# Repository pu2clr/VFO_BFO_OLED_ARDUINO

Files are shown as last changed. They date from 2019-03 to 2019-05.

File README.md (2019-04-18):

# VFO and BFO with Si5351A, OLED and Arduino

## By PU2CLR - Ricardo Lima Caratti - March 18th, 2019

__Português:__ Gerador de Sinal com Si5341, OLED e Arduino. Este projeto é sobre a construção de um VFO (530KHz to 160MHz) e um BFO (452KHz to 458KHz). Para mais detalhes consulte a [documentação em Português](/Doc/Pt). 

__English:__ Signal Generetor with Si5351, OLED and Arduino. This project is about a construction of a VFO (530KHz to 160MHz) and a BFO (452KHz to 458KHz or another range). See [documentation here](/Doc/En).

## Table of contents

1. [Introduction](/Doc/En#introduction) 
1. [Arduino ATmega32U4](/Doc/En#arduino-atmega32u4)
1. [BFO interface](/Doc/En#vfo-and-bfo-interface)
	1. [VFO and BFO and Dial information](/Doc/En#vfo-and-bfo-and-dial-information)
1. [Band table for the VFO](/Doc/En#band-table-for-the-VFO)
1. [Schematic](/Doc/En#schematic)
1. [Components](/Doc/En#components)
1. [Arduino sketch](/Doc/En#arduino-sketch)
	1. [BFO range](/Doc/En#bfo-range)
	1. [Arduino pins and  Encoder, Band, Step and Switch VFO/BFO](/Doc/En#arduino-pins-and--encoder-band-step-and-switch-vfobfo)
	1. [Bands and frequency ranges](/Doc/En#bands-and-frequency-ranges)
	1. [External interrupts](/Doc/En#external-interrupts)
	1. [Changing the kind of display device](/Doc/En#changing-the-kind-of-display-device)
	1. [SI5351 Calibration](/Doc/En#sI5351-calibration)
1. [Photos](/Doc/En#photos)
1. [Expetiments and Applications](https://github.com/pu2clr/VFO_BFO_OLED_ARDUINO/tree/master/Experiments)
   1. [The BFO and VFO impplemented on Atmega328 (without use of external interruptions)](https://github.com/pu2clr/VFO_BFO_OLED_ARDUINO/tree/master/Experiments/Atmega328)  
   2. [IR Remote Control Implemetation for the VFO and BFO (Atmega328)](https://github.com/pu2clr/VFO_BFO_OLED_ARDUINO/tree/master/Experiments/IRController)
   3. [VFO and BFO project with a inexpencive radio based on CD2003GP](https://github.com/pu2clr/VFO_BFO_OLED_ARDUINO/tree/master/Experiments/VFO_RADIO_CD2003GP)
2. [References](/Doc/En#references)
3. [Videos](/Doc/En#videos)

## Photo

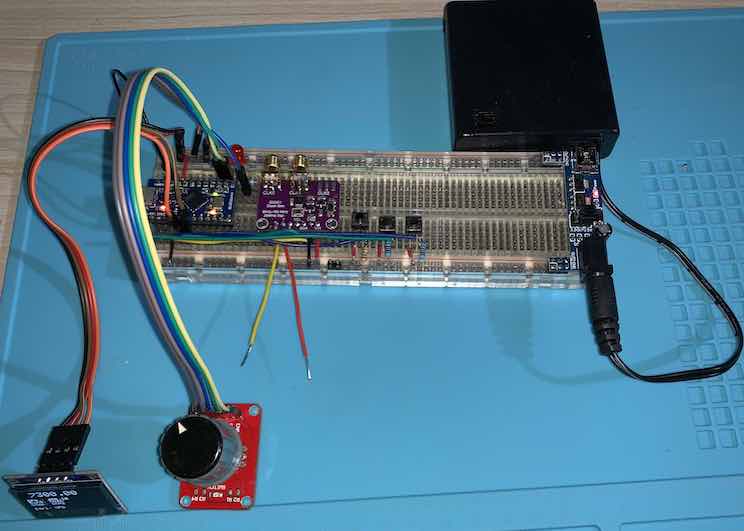
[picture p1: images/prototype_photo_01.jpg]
Photo about this project
 

## Short links

- Click [here](https://youtu.be/pFDvcIk5EAk) to see the video about this project.
- Click [here](https://github.com/pu2clr/VFO_BFO_OLED_ARDUINO/tree/master/Doc/En) for documentation
- Click [here](/source/si5351_vfobfo.ino) to see Arduino Sketch

## About the author 

I studied for four years Electrical Engineering at the University of Fortaleza, Ceará, Brazil, but I ended up majoring in IT area at UPIS, Brasília, Brazil. In 2007 I got post-graduate degree in Distributed Systems at University of Brasilia (UNB). From 1985 to 1998, I worked as a Developer using C/C++, FORTRAN and ALGOL Programming Languages at Federal University of Ceara (Universidade Federal do Ceará). From 1998 to 2010 I worked as a database administrator in several companies. Currently working as an independent consultant in the field of Information Technology. In 2009 I wrote the book "Joomla! Avançado" (translated to English could be Advanced Joomla!); In 2012, after almost 30 years far from electronics, I returned to my old hobby and also got my amateur radio license.

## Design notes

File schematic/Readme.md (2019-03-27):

# The Arduino and components wire up.

This schematic was made by using the <a href="http://fritzing.org/home/">Fritzing Software</a>.  

The  <a href="http://fritzing.org/home/">Fritzing file is available in this repository</a>. 

## Schematic
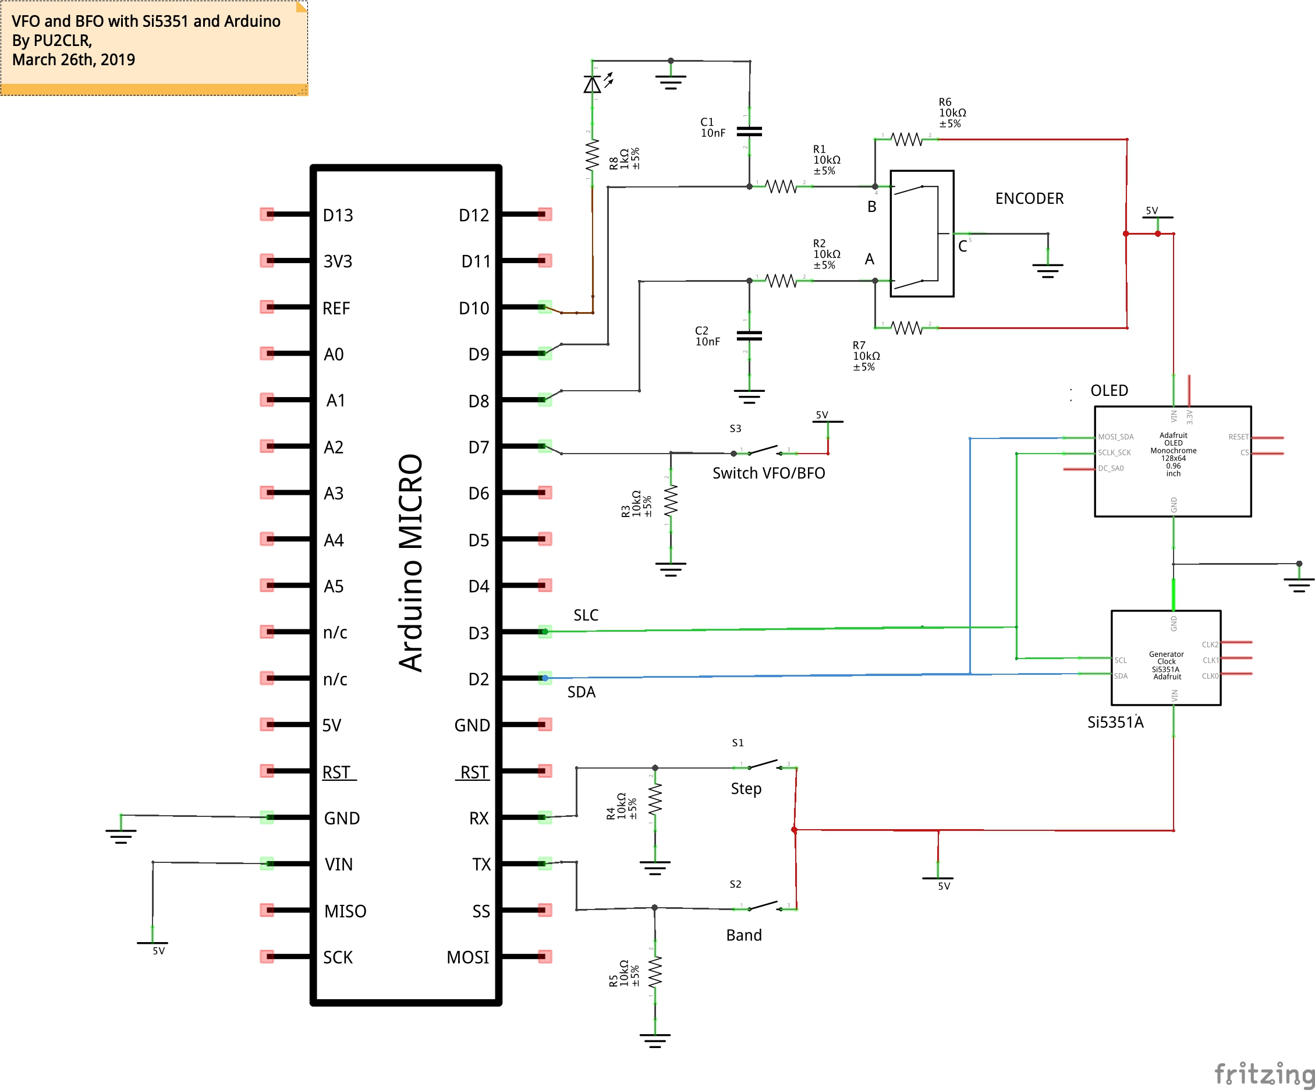
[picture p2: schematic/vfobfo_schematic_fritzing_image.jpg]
VFO and BFO schematic
 

### Si5351A

The __Si5351A__ is connected to D2 (SDA) and  D3 (SCL).

### OLED Display SSD1306 - 128 x 64/0.96

The __OLED__ is connected to D2 (SDA) and  D3 (SCL). Yes, the same Si5351A connections.

### Encoder

Connect Arduino __D8__ and __D9__ pins to the __Encoder__ pin __A__ and pin __B__ respectively.

### Push Button Band

Connect Arduino __D0/Rx__ pin to the __Band__ push button.

### Push Button Step

Connect Arduino __D1/Tx__ pin to the __Step__ push button. 

### Push Button VFO/BFO

Connect Arduino __D7__ pin to the __VFO/BFO__ push button.

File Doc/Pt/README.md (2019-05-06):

# Projeto do VFO e BFO com Si5351A e Arduino

# Sumário

* [Introdução](/Doc/Pt#introdução)
* [SI5351](/Doc/Pt#si5351)
* [Arduino ATmega32U4](/Doc/Pt#arduino-atmega32u4)
* [Operação do VFO e BFO](/Doc/Pt#operação-do-vfo-e-bfo)
* [Informações VFO and BFO no display (Dial)](/Doc/Pt#informa%C3%A7%C3%B5es-vfo-and-bfo-no-display-dial)
* [Tabela de divisão de Bandas utilizadas no Projeto](/Doc/Pt#tabela-de-divisão-de-bandas-utilizadas-no-projeto)
* [Esquema Elétrico](/Doc/Pt#esquema-elétrico)
  *  [Si5351A](/Doc/Pt#si5351a)
	* [OLED Display SSD1306 - 128 x 64/0.96](/Doc/Pt#oled-display-ssd1306---128-x-64096)
	* [Endoder](/Doc/Pt#encoder)
* [Sobre o programa Arduino](/Doc/Pt#sobre-o-esquema-e-conexões)
  * [Calibração do Si5351A](/Doc/Pt#calibração-do-si5351a)
	* [Modificando a faixa de frequência do BFO](/Doc/Pt#modificando-a-faixa-de-frequ%C3%AAncia-do-bfo)
	* [Alterando as Bandas e Frequências do VFO](/Doc/Pt#modificando-a-faixa-de-frequ%C3%AAncia-do-vfo)
	* [Alterando a configuração de passos de incremento e decremento](/Doc/Pt#alterando-a-configura%C3%A7%C3%A3o-de-passos-de-incremento-e-decremento)
	* [Alterando as configurações dos pinos do Arduino para Banda, Step, VFO/BFO e Encoder](/Doc/Pt#alterando-as-configura%C3%A7%C3%B5es-dos-pinos-do-arduino-para-banda-step-vfobfo-e-encoder)
	* [Interrupções externas](/Doc/Pt#interrupções-externas)
	* [Modificando o tipo de Display](/Doc/Pt#modificando-o-tipo-de-display)
* [Considerações finais](/Doc/Pt#considerações-finais)
* [Fotos](/Doc/Pt#fotos)
* [Experimentos e Aplicações](https://github.com/pu2clr/VFO_BFO_OLED_ARDUINO/tree/master/Experiments)
  * [BFO e VFO implementado no Atmega328 (Sem uso de interrupções)](https://github.com/pu2clr/VFO_BFO_OLED_ARDUINO/tree/master/Experiments/Atmega328)  
  * [Controle Remoto Infravermelhor para o VFO and BFO (Atmega328)](https://github.com/pu2clr/VFO_BFO_OLED_ARDUINO/tree/master/Experiments/IRController)
  * [Testando o VFO and BFO em um rádio barato baseado no CD2003GP](https://github.com/pu2clr/VFO_BFO_OLED_ARDUINO/tree/master/Experiments/VFO_RADIO_CD2003GP/Docs)
* [Referências](/Doc/Pt#considerações-finais)
* [Vídeos](/Doc/Pt#v%C3%ADdeos)

## Introdução

Este projeto é baseado no gerador de sinal Si5351A que permite operações com alta frequência.  Assim, o VFO deste projeto pode oscilar entre 100KHz e 160MHz. Esta  extensa faixa de frequencia foi dividida em 27 bandas que podem ser mudadas via o pressionamento de um botão (veja tabela a seguir). Um encoder permite que você mude a frequência dentro de uma banda. Quanto ao  BFO, foi projetado para oscilar entre 452KHz e 458KHz.  Um outro botão alterna o controle entre o VFO e o BFO. A frequência do BFO pode ser alterada pelo encoder.  O <B>programa em Arduino  está disponível</B> na pasta <B>source</B> deste repositório ou diretamente por este [link](/source/si5351_vfobfo.ino) e poderá ser adaptado conforme a sua necessidade.  A documentação do código fonte foi escrita no idioma Inglês, porém, não creio que isso será um problema para a maioria dos desenvolvedores. Qualquer dúvida ou problema poderá ser postado via a <a href="https://github.com/pu2clr/VFO_BFO_OLED_ARDUINO/issues">aba Issues</a> . Além do projeto base descrito anteriormente, há algumas adaptações do projeto que podem ser conferidas na pasta [Experiments]( https://github.com/pu2clr/VFO_BFO_OLED_ARDUINO/tree/master/Experiments). Nesta pasta você encontrará modificações do VFO e BFO para trabalhar com controle remoto [Infravermelho]( https://github.com/pu2clr/VFO_BFO_OLED_ARDUINO/tree/master/Experiments/IRController), [Implementação para Arduino Uno, Mini, Nano etc]( https://github.com/pu2clr/VFO_BFO_OLED_ARDUINO/tree/master/Experiments/Atmega328), [Usando o VFO em um rádio baseado no chip CD2003GP]( https://github.com/pu2clr/VFO_BFO_OLED_ARDUINO/tree/master/Experiments/VFO_RADIO_CD2003GP/Docs), entre outras aplicações que podem ser conferidas exploradas na referida pasta.     

## SI5351

O Si5351A é um gerador de sinal configurável excelente para experimentações em radioamadorismo. Ele possui três saídas de sinal que podem ser configuradas de forma  independente por meio de um microcontrolador. Isto é, cada saída pode oscilar em uma frequência distinta da outra. Esta característica permite, por exemplo, a construção de um VFO e um BFO no mesmo ambiente,simplificando circuitos em receptores e transmissores. Há também inúmeras aplicações para o si5351. Para mais informações sobre o si5351 clique [aqui](https://www.silabs.com/documents/public/data-sheets/Si5351-B.pdf).

## Arduino ATmega32U4 

Este projeto utiliza o Arduino baseado no ATmega32U4. Versões do arduino com o Atmega32u4 tem 5 pinos com recurso de [interrupções externas](/Doc/Pt#interrupções-externas) (pinos 0,1,2,3 e 7). Este recurso é útil neste projeto para implementar a execução de algumas funções, independente do fluxo de execução normal do Arduino, em especial o pressionamento dos botões Band, Step e VFO/BFO. É importante ressaltar que as mesmas funções poderiam ser implementadas sem o uso desses recurso. Para mais informações sobre o Arduino baseado no Atmega32u4 clique [aqui](https://store.arduino.cc/usa/arduino-micro). 

## Operação do VFO e BFO

O usuário poderá controlar o VFO e o BFO por três botões e um Encoder

- O	botão **Band** muda a faixa de freqência. Este projeto divide o VFO em 27 faixas. Veja a tabela de bandas a seguir;
- O botão **VFO/BFO** alterna o controle entre o VFO e o BFO.
- O botão **Step** muda o passo de incremento e decremento. Pode ser 50Hz, 100Hz, 500Hz, 1KHz, 2.5KHz, 5KHz, 10KHz, 100KHz e 500KHz;
- O **Encoder** é utilizado para controlar a frequência do VFO ou BFO.

### Informações VFO and BFO no display (Dial)

O Dial deste projeto utiliza um [OLED Display 128 x 64 Pixels White 0.96 Inch I2C LED](https://startingelectronics.org/tutorials/arduino/modules/OLED-128x64-I2C-display/). As ações do usuário nos botões Band, Step e VFO/BFO, bem como as frequências correntes no VFO e BFO são apresentadas neste display a cada mudança de status. Dado o tamanho reduzido deste display, é possível que você queira utilizar um outro tipo de display. Para tanto, siga as recomendações no item [Modificando o tipo de Display](/Doc/Pt#modificando-o-tipo-de-display) neste documento. A tabela a seguir ilustra as informações do display utilizado neste projeto. 

|  Dial Information | Dial Information |
| --- | --- |
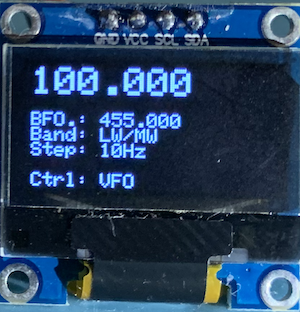
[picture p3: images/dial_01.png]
Photo dial 01
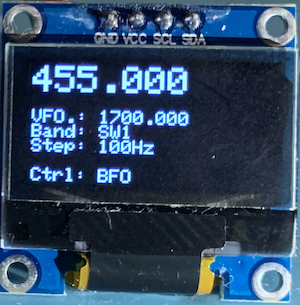
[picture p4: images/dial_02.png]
Photo dial 02
| |   |
| VFO está em 100 KHz; BFO está em 455 KHz; a banda é LW/MW; passo de incremento é 10Hz; e o encoder está controlando o VFO | Neste caso o encoder está controlando o BFO; note que a frequência do BFO passou a ser apresentada na primeira linha(destacada)| 
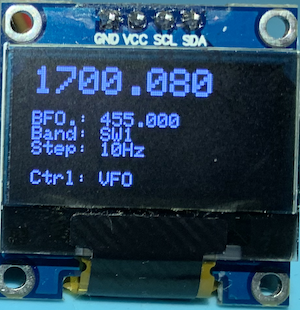
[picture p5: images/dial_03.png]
Photo dial 03
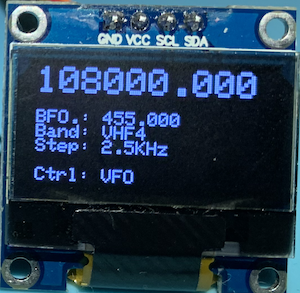
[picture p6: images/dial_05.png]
Photo dial 04
| |   |
| VFO está em 1700.08 KHz; BFO está 455 KHz; a banda é SW1; o passo de incremento é 10Hz; e o encoder está controlando o VFO | VFO está 108MHz; BFO está em 455 KHz; a banda é VFH4, o passo de incremento é 2.5KHz; e o encoder está controlando o VFO | 

## Tabela de divisão de Bandas utilizadas no Projeto

O VFO está dividido em 27 bandas. A primeira banda varia entre 100KHz até 1.7MHz e a última banda varia entre 135MHz até 160MHz. É possível que você queira reduzir o número de bandas ou mesmo alterar as frequências em cada banda. Para tanto, consulte a adiante ["Sobre o programa Arduino"](/Doc/Pt#sobre-o-esquema-e-conexões).

<table cellspacing="0" border="0">
	<colgroup width="37"></colgroup>
	<colgroup width="91"></colgroup>
	<colgroup width="106"></colgroup>
	<colgroup width="111"></colgroup>
	<tr>
		<td height="23" align="left">N#</td>
		<td align="left">Band</td>
		<td align="left">From</td>
		<td align="left">to</td>
	</tr>
	<tr>
		<td height="23" align="right" sdval="1" sdnum="1046;">1</td>
		<td align="left">LW/MW   </td>
		<td align="left"> 100 KHz</td>
		<td align="left"> 1.7 MHz</td>
	</tr>
	<tr>
		<td height="23" align="right" sdval="2" sdnum="1046;">2</td>
		<td align="left">SW1  </td>
		<td align="left"> 1.7 MHz</td>
		<td align="left"> 3.5 MHz</td>
	</tr>
	<tr>
		<td height="23" align="right" sdval="3" sdnum="1046;">3</td>
		<td align="left">SW2  </td>
		<td align="left"> 3.5 MHz</td>
		<td align="left"> 4.0 MHz</td>
	</tr>
	<tr>
		<td height="23" align="right" sdval="4" sdnum="1046;">4</td>
		<td align="left">SW3  </td>
		<td align="left"> 4.0 MHz</td>
		<td align="left"> 7.0 MHz</td>
	</tr>
	<tr>
		<td height="23" align="right" sdval="5" sdnum="1046;">5</td>
		<td align="left">SW4  </td>
		<td align="left"> 7.0 MHz</td>
		<td align="left"> 7.3 MHz</td>
	</tr>
	<tr>
		<td height="23" align="right" sdval="6" sdnum="1046;">6</td>
		<td align="left">SW5  </td>
		<td align="left"> 7.3 MHz</td>
		<td align="left"> 9.0 MHz</td>
	</tr>
	<tr>
		<td height="23" align="right" sdval="7" sdnum="1046;">7</td>
		<td align="left">SW6  </td>
		<td align="left"> 9.0 MHz</td>
		<td align="left"> 10.0 MHz</td>
	</tr>
	<tr>
		<td height="23" align="right" sdval="8" sdnum="1046;">8</td>
		<td align="left">SW7  </td>
		<td align="left"> 10.0 MHz</td>
		<td align="left"> 11.0 MHz</td>
	</tr>
	<tr>
		<td height="23" align="right" sdval="9" sdnum="1046;">9</td>
		<td align="left">SW8  </td>
		<td align="left"> 11.0 MHz</td>
		<td align="left"> 14.0 MHz</td>
	</tr>
	<tr>
		<td height="23" align="right" sdval="10" sdnum="1046;">10</td>
		<td align="left">SW9  </td>
		<td align="left"> 14.0 Mhz</td>
		<td align="left"> 15.0 MHz</td>
	</tr>
	<tr>
		<td height="23" align="right" sdval="11" sdnum="1046;">11</td>
		<td align="left">SW10 </td>
		<td align="left"> 15.0 MHz</td>
		<td align="left"> 17.0 MHz</td>
	</tr>
	<tr>
		<td height="23" align="right" sdval="12" sdnum="1046;">12</td>
		<td align="left">SW11 </td>
		<td align="left"> 17.0 MHz</td>
		<td align="left"> 18.0 MHz</td>
	</tr>
	<tr>
		<td height="23" align="right" sdval="13" sdnum="1046;">13</td>
		<td align="left">SW12 </td>
		<td align="left"> 18.0 MHz</td>
		<td align="left"> 20.0 MHz</td>
	</tr>
	<tr>
		<td height="23" align="right" sdval="14" sdnum="1046;">14</td>
		<td align="left">SW13 </td>
		<td align="left"> 20.0 MHz</td>
		<td align="left"> 21.35 MHz</td>
	</tr>
	<tr>
		<td height="23" align="right" sdval="15" sdnum="1046;">15</td>
		<td align="left">SW14 </td>
		<td align="left"> 21.35 MHz</td>
		<td align="left">22.00 MHz</td>
	</tr>
	<tr>
		<td height="23" align="right" sdval="16" sdnum="1046;">16</td>
		<td align="left">SW15 </td>
		<td align="left"> 22.0 MHz</td>
		<td align="left"> 24.88 MHz</td>
	</tr>
	<tr>
		<td height="23" align="right" sdval="17" sdnum="1046;">17</td>
		<td align="left">SW16 </td>
		<td align="left"> 24.88 MHz</td>
		<td align="left"> 24.99 MHz</td>
	</tr>
	<tr>
		<td height="23" align="right" sdval="18" sdnum="1046;">18</td>
		<td align="left">SW17 </td>
		<td align="left"> 24.99 MHz</td>
		<td align="left"> 26.0 MHz</td>
	</tr>
	<tr>
		<td height="23" align="right" sdval="19" sdnum="1046;">19</td>
		<td align="left">SW18 </td>
		<td align="left"> 26.0 MHz</td>
		<td align="left"> 28.0 MHz</td>
	</tr>
	<tr>
		<td height="23" align="right" sdval="20" sdnum="1046;">20</td>
		<td align="left">SW19 </td>
		<td align="left"> 28.0 MHz</td>
		<td align="left"> 30.0 MHz</td>
	</tr>
	<tr>
		<td height="23" align="right" sdval="21" sdnum="1046;">21</td>
		<td align="left">VHF1 </td>
		<td align="left"> 30.0 MHz</td>
		<td align="left"> 50.0 MHz</td>
	</tr>
	<tr>
		<td height="23" align="right" sdval="22" sdnum="1046;">22</td>
		<td align="left">VHF2 </td>
		<td align="left"> 50.0 MHz</td>
		<td align="left"> 54.0 MHz</td>
	</tr>
	<tr>
		<td height="23" align="right" sdval="23" sdnum="1046;">23</td>
		<td align="left">VHF3 </td>
		<td align="left"> 54.0 MHz</td>
		<td align="left"> 86.0 MHz</td>
	</tr>
	<tr>
		<td height="23" align="right" sdval="24" sdnum="1046;">24</td>
		<td align="left">FM   </td>
		<td align="left"> 86.0 MHz</td>
		<td align="left"> 108.0 MHz</td>
	</tr>
	<tr>
		<td height="23" align="right" sdval="25" sdnum="1046;">25</td>
		<td align="left">VHF4 </td>
		<td align="left"> 108.0 MHz</td>
		<td align="left"> 120.0 MHz </td>
	</tr>
	<tr>
		<td height="23" align="right" sdval="26" sdnum="1046;">26</td>
		<td align="left">VHF5 </td>
		<td align="left"> 120.0 MHz</td>
		<td align="left"> 135.0 MHz</td>
	</tr>
	<tr>
		<td height="23" align="right" sdval="27" sdnum="1046;">27</td>
		<td align="left">VHF6 </td>
		<td align="left"> 135.0 MHz</td>
		<td align="left"> 160.0 MHz</td>
	</tr>
</table>

## Esquema Elétrico

<P> A figura a seguir ilustra o esquema elétrico envolvendo os componentes utilizados no projeto. </P>

 Esquema do Projeto VFO e BFO com Arduino

### Sobre o esquema e conexões

Para este projeto foi utilizado o Arduino Micro, baseado no _Atmega32u4_. A principal razão pela escolha desta versão do Arduino foi pelo fato dele possibilitar o uso de até 5 interrupções externas (pinos 0, 1, 2, 3, 7). Este recurso foi utilizado para implementar o funcionamento dos botões Band, Setp e switch VFO / BFO. No entanto, com poucos ajustes no projeto, é possível adaptá-lo para um Arduino UNO ou similar. 

__Importante__:
Se você não tiver um Arduino baseado no _Atmega32u4_, há um outro sketch para Arduino desenvolvido sem o uso do recurso de interrupção externa disponível na pasta [source/Atmega328](/https://github.com/pu2clr/VFO_BFO_OLED_ARDUINO/tree/master/source/Atmega328), apropriado para o Arduino UNO, Mini, Nano etc, que poderá ajudá-lo. Este sketch foi desenvolvido somente para ilustrar como usar as fucionalidades dos botões na função __loop()__. No entanto, este sketch não é objeto principal deste projeto e __não__ será atualizado. Quero dizer, novas funcionalidades e correções só serão incorporadas no código para o _Atmega32u4_.

#### Si5351A
O dispositivo Si5351A é ligado nos pinos D2 e D3 do Arduino (MICRO ou compatível). Você deve ficar atendo às descrições SDA (pin D2) e SCL (pin D3). A inversão dessas conexões fará com que o dispositivo não funcione. 

#### OLED Display SSD1306 - 128 x 64/0.96
OLED Display também é ligado aos pinos D2 e D3 do Arduino Micro obedecendo as mesmas orientações do Si5351A. 

### Encoder
O encoder é conectado ao Arduino Micro da seguinte forma: terminal A no pino D8 e terminal B no pino D9.
É recomendado a utilizacao de um filtro RC, implementado no esquema acima por dois capacitores de 10nF e dois resistores de 10K. Esta técnica permite que sinais indesejados causados pelos contatos metálicos do encoder durante a sua rotação sejam enviados para os pinos do Arduino.

#### Botão de Banda (Band)

O Push Button Band é conectado ao pino D0/Rx conforme mostra a figura anterior. Este botão permite a seleção de 27 bandas.

#### Botão de Passo (Step)

O Push Button Step é conectado ao pino D1/TX. 
Este botão permite a seleção do passo de incremento e decremento da frequência quando o encoder for girado. 

#### Botão switch VFO/BFO

O Push Button VFO/BFO é conectado ao pino D7. 
Este botão alterna o controle da frequência do VFO para BFO e vice-versa.

É importante ter em mente que, no caso do Arduino Micro, os pinos D2 e D3 são os que implementam o SDA e o SCL respectivamente. Outras versões de Arduino utilizam outros pinos para essas funções. 

## Sobre o programa Arduino

O programa (sketch) Arduino <a href="https://github.com/pu2clr/VFO_BFO_OLED_ARDUINO/blob/master/source/si5351_vfobfo.ino">disponível neste projeto</a>, pode ser livremente baixado, modificado e utilizado por qualquer um que tenha interesse em desenvolver um projeto similar.  

Para controlar o Si53551A via Arduino foi utilizado a <a href="https://github.com/etherkit/Si5351Arduino">biblioteca Etherkit (Si5351 Library for Arduino)</a> desenvolvida pelo radioamador NTS7. Esta biblioteca oferece uma documentação muito rica e com várias facilidades se comparadas a outras bibliotecas para o Si5351. 

Ainda em relação a biblioteca da Etherkit, é importante observar o mecanismo de __calibração__ do Si5351. 
Existe um exemplo (si5351_calibration) que vem com a biblioteca da Etherkit que permite a calibração do Si5351. Este procedimento melhora a precisão da frequência de saída do sinal gerado pelo SI5351. Publiquei um vídeo no Youtube que mostrar como calibrar o Si5351 se necessário. Clique <a href="https://youtu.be/BJ83uvDcfIo">aqui</a> para assistir ao vídeo.

### Calibração do Si5351A

No <a href="https://github.com/pu2clr/VFO_BFO_OLED_ARDUINO/blob/master/source/si5351_vfobfo.ino">Sketch</a> deste projeto, você encontrará algumas linhas de código que se referem à correção do Si5351 necessária para melhorar a sua precisão. Caso necessário, [este vídeo](https://youtu.be/BJ83uvDcfIo) ilustra como fazer a Calibração do Si5351. O código a seguir ilustra a utilização do fator de correção encontrado no processo de calibração. 

```cpp

#define CORRECTION_FACTOR 80000 // See how to calibrate your Si5351A (0 if you do not want).
.
.
.
void setup()
{
  .
  .
  si5351.init(SI5351_CRYSTAL_LOAD_8PF, 0, 0);
  // Adjusting the frequency (see how to calibrate the Si5351 - example si5351_calibration.ino)
  si5351.set_correction(CORRECTION_FACTOR, SI5351_PLL_INPUT_XO);
  .
  .

}
.
````

Note no código anterior que a constante definida __CORRECTION_FACTOR__ tem o valor 80000. Este valor foi encontrado na execução do Sketch si5351_correction (ver exemplo no IDE do arduino).
Note também que após instanciar e iniciar o Si5351, a função si5351.set_correction(CORRECTION_FACTOR, SI5351_PLL_INPUT_XO) é executada. Este chamada permite fazer a correção da frequência do gerador de sinal.

__Importante:__ Se você não executou o processo de calibração do seu Si5351 e não pretende fazer isto, ajuste a constante definida CORRECTION_FACTOR para 0 como mostrado a seguir:

```cpp
#define CORRECTION_FACTOR 0 
```

### Informações sobre a configuração do  VFO e BFO 

Alguns parâmetros utilizados no código-fonte podem ser alterados para atender alguma demanda específica quanto à pinagem do Arduino, bandas e frequências  utilizadas pelo VFO, bem como os limites e a frequência para o BFO.

### Modificando a faixa de frequência do BFO

Originalmente o BFO deste projeto está configurado para operar em 455KHz conforme apresentado no código a seguir: 

```cpp
#define MAX_BFO     45200000LU    // BFO max. frequency
#define CENTER_BFO  45500000LU    // BFO center frequency
#define MIN_BFO     45800000LU    // BFO min. frequency
````

O código a seguir modifica o BFO para operar em 10MHz

```cpp
#define MAX_BFO      990000000LU    // BFO max. frequency
#define CENTER_BFO  1000000000LU    // BFO center frequency
#define MIN_BFO     1100000000LU    // BFO min. frequency 
```
O código anterior altera o BFO para oscilar entre 9.9MHZ e 10.1MHz. Lembrando que a unidade utilizada pela biblioteca si5351.h é 0.01Hz (um centésimo de Hertz).

### Modificando a faixa de frequência do VFO

Este projeto definiu 27 bandas (faixas de frequência) que cobrem de 535KHz a 160MHz. A quantidade de bandas, bem como os limites inferiores e superiores de cada banda podem ser alteradas na estrutura apresentada no código a seguir:

```cpp
// Band database. You can change the band ranges if you need.
// The unit of frequency here is 0.01Hz (1/100 Hz). See Etherkit Library at https://github.com/etherkit/Si5351Arduino
Band band[] = {
    {"LWMW ", 53500000LLU, 170000000LLU},     // 100KHz to 1700KHz
    {"SW1  ", 170000000LLU, 350000000LLU},
    {"SW2  ", 350000000LLU, 400000001LLU},
    {"SW3  ", 400000000LLU, 700000000LLU},
    {"SW4  ", 700000000LLU, 730000000LLU},    // 7MHz to 7.3 MHz  (Amateur 40m)
    {"SW5  ", 730000000LLU, 900000000LLU},    // 41m
    {"SW6  ", 900000000LLU, 1000000000LLU},   // 31m
    {"SW7  ", 1000000000LLU, 1100000000LLU},  // 10 MHz to 11 MHz (Amateur 30m)
    {"SW8  ", 1100000000LLU, 1400000000LLU},  // 25 and 22 meters
    {"SW9  ", 1400000000LLU, 1500000000LLU},  // 14MHz to 15Mhz (Amateur 20m)
    {"SW10 ", 1500000000LLU, 1700000000LLU},  // 19m
    {"SW11 ", 1700000000LLU, 1800000000LLU},  // 16m
    {"SW12 ", 1800000000LLU, 2000000000LLU}, // 18MHz to 20Mhz (Amateur and comercial 15m)
    {"SW13 ", 2000000000LLU, 2135000000LLU}, // 20MHz to 22Mhz (Amateur and comercial 15m/13m)
    {"SW14 ", 2135000000LLU, 2200000000LLU},
    {"SW15 ", 2235000000LLU, 2498000000LLU},
    {"SW16 ", 2488000000LLU, 2499000000LLU}, // 24.88MHz to 24.99MHz (Amateur 12m)
    {"SW17 ", 2499000000LLU, 2600000000LLU},
    {"SW18 ", 2600000000LLU, 2800000000LLU},
    {"SW19 ", 2800000000LLU, 3000000000LLU}, // 28MHz to 30MHz (Amateur 10M)
    {"VHF1 ", 3000000000LLU, 5000000000LLU},
    {"VHF2 ", 5000000000LLU, 5400000000LLU},
    {"VHF3 ", 5400000000LLU, 8600000000LLU},
    {"FM   ", 8600000000LLU, 10800000000LLU},  // Comercial FM
    {"VHF4 ", 10800000000LLU, 12000000000LLU}, // 108MHz to 160MHz
    {"VHF5 ", 12000000000LLU, 13500000000LLU}, // Air band
    {"VHF6 ", 13500000000LLU, 16000000000LLU}}; 

// Calculate the last element position (index) of the array band 
const int lastBand = (sizeof band / sizeof(Band)) - 1; // For this case will be 26.
volatile int currentBand = 0; // First band. For this case, AM is the current band.
```

### Alterando a configuração de passos de incremento e decremento

Os valores do passo de incremento e decremento, bem como as faixas utilizadas podem ser modificadas alterando o trecho de código a seguir: 

```cpp
// Steps database. You can change the Steps and numbers of steps here if you need.
Step step[] = {
    {"50Hz  ", 5000},         // VFO and BFO min. increment / decrement 
    {"100Hz ", 10000},
    {"500Hz ", 50000},
    {"1KHz  ", 100000},       // BFO max. increment / decrement
    {"2.5KHz", 250000},
    {"5KHz  ", 500000},
    {"10KHz ", 1000000},
    {"100KHz", 10000000},
    {"500KHz", 50000000}};    // VFO max. increment / decrement
// Calculate the index of last position of step[] array (in this case will be 8)
const int lastStepVFO = (sizeof step / sizeof(Step)) - 1; // index for max increment / decrement for VFO
volatile int lastStepBFO = 3;   // index for max. increment / decrement for BFO. In this case will be is 1KHz
volatile long currentStep = 0;  // it stores the current step index (50Hz in this case)
```

### Alterando as configurações dos pinos do Arduino para Banda, Step, VFO/BFO e Encoder

Da mesma forma, os Botões, o Encoder e o LED, podem ser instalados em outros pinos do Arduino que não os utilizados neste projeto. Para tanto, basta modificar os valores para as constantes definidas no código a seguir. Contudo, é importante que os botões devem estar conectados aos pinos do Arduino ou similar com suporte à interrupções externas.  

```cpp
#define ENCODER_PIN_A 8 // Arduino  D8
#define ENCODER_PIN_B 9 // Arduino  D9

#define BUTTON_STEP 0    // Control the frequency increment and decrement
#define BUTTON_BAND 1    // Controls the band
#define BUTTON_VFO_BFO 7 // Switch VFO to BFO
```

### Explicando como o encoder foi codificado

Não uso interrupção nem uma biblioteca específica para encoder. Simplesmente leio os pinos do encoder.

O primeiro passo é informar ao Arduino que os pinos do Encoder são somente de ENTRADA (INPUT). Ver função setup().

```cpp
 pinMode(ENCODER_PIN_A, INPUT);
 pinMode(ENCODER_PIN_B, INPUT);
```

Depois declaro as variáveis de controle do encoder (incluindo o tempo mínimo para a processar a próxima ação)

```cpp
long elapsedTimeEncoder = millis();

// Encoder variable control
unsigned char encoder_pin_a;
unsigned char encoder_prev = 0;
unsigned char encoder_pin_b;
```

O tipo unsigned char é na realidade um número inteiro, não sinalizado de 8 bits. Ele admite valores entre 0 e 255.  Poderia ser um int. A questão aqui é de economia de memória e de cíclo de máquina.

a variável __encoder_prev__ armazena a última ação do encoder. Dessa forma, na iteração corrente, é póssivel fazer comparação com a ação anterior do encoder.

Na função  loop(), o processo inicia checando se já ocorreu mais de 5 milisegundos após a última ação do encoder.  Caso não tenha ocorrido mais de 5 milissegundos, não efetua as leituras nos pinos do encoder (ignora o encoder). Isso é útil para eliminar efeitos indesejáveis causados pelo mal contato das placas metálicas do encoder (ver Debounce);

```cpp
if ((millis() - elapsedTimeEncoder) > 5)
  {
    encoder_pin_a = digitalRead(ENCODER_PIN_A);
    encoder_pin_b = digitalRead(ENCODER_PIN_B);
    if ((!encoder_pin_a) && (encoder_prev)) // has ENCODER_PIN_A gone from high to low?
    {                                       // if so,  check ENCODER_PIN_B. It is high then clockwise (1) else counter-clockwise (-1)
      changeFreq(((encoder_pin_b) ? 1 : -1));
    }
    encoder_prev = encoder_pin_a;
    elapsedTimeEncoder = millis(); // keep elapsedTimeEncoder updated
  }
 ```

caso o tempo decorrido entre a última ação do encoder e o tempo atual for maior que 5 milissegundos, eu leio os dois pinos em que o encoder está conectado.

se o pino A (__encoder_pin_a__) estiver em nível lógico baixo (0) e o __encoder_prev__ (situação anterior deste pino) estiver em nível lógico alto (1), então é porque houve mudança no estado do encoder (houve giro).
Lemvrando que __!encoder_pin_a__ poderá ter os seguintes resultados: se encoder_pin_a for 0, o resultado será 1 (verdadeiro); se  encoder_pin_a for 1, o resultado será 0 (falso).

Se a expressão __if ((!encoder_pin_a) && (encoder_prev))__  for verdadeira, então houve giro no encoder. Agora é preciso determinar qual o sentido (horário ou anti-horário). Quem vai dizer isso é estado do __encoder_pin_b_. 
Se __encoder_pin_b__ estiver em nível lógico alto (1), então é sentido horário. Caso contrário, nível lógico baixo (0), é anti-horário.
A linguagem C permite uma atribuição condicional na forma apresentada no exemplo a seguir: 

```cpp
X = ( A > B)? 1:-1); 
```
Neste exemplo, X recebe 1 se A for maior que B; caso contrário, recebe -1.

Observe a expressão dentro da chamada da função changeFreq():

```cpp
((encoder_pin_b) ? 1 : -1)
```

A função __changeFreq()__ recebe dois possíveis valores como parâmetros: 1 para incrementar a frequência (sentido horário do encoder); e -1 para decrementar (sentido anti-horário). 
se __encoder_pin_b__ for 1, então changeFreq() será chamada com o valor 1 (equivalente à chamada changeFreq(1)). Caso contrário, __encoder_pin_b__ for igual a 0, changeFreq() será chamada com o valor -1 (equivalente à chamada changeFreq(-1)).

Note que dentro do bloco atendida pela condição do encoder __[if ((millis() - elapsedTimeEncoder) > 5)]__, a ação corrente da variável __encoder_pin_a__ é armazenada na variável ___encoder_prev__. E também é atualizado o tempo em __elapsedTimeEncoder__.

```cpp
    encoder_prev = encoder_pin_a;
    elapsedTimeEncoder = millis(); // keep elapsedTimeEncoder updated
```

com isso, após 5 milissegundos,  os pinos do encoder poderão ser lidos novamente e também ser feita a verificação de giro do encoder. 

### Interrupções externas

Este projeto implementa os três botões (Band, Step e Switch VFO/BFO) usando o recurso interrupções externas do Arduino. No caso do Atmega32u4, os pinos 0,1,2,3 e 7 podem ser utilizados para esta finalidade. Desta forma, quando um dos botões for pressionado, o Arduido interroperá o fluxo de execução normal para executar o códio conectado a interrupção.  Entenda mais sobre Interrupções no Arduino clicando [aqui](https://www.arduino.cc/reference/pt/language/functions/external-interrupts/attachinterrupt/).

O uso de interrupção para executar as ações dos botões é especialmente útil neste projeto porque facilita a execução imediata da função desejada no momento do pressionamento do botão. Obviamente é possível implementar as ações dos botões Band, Step e switch VFO/BFO na função loop do Arduino usando a abordagem tradicional. No entanto, esta abordagem pode causar algumas imprecisões quanto à resposta do sistema no momento do pressionamento do botão.  Infelizmente, dada a pouca quantidade de pinos no Arduino baseado no Atmega32u4 que implementa interrupções externas, não foi possível usar o mesmo recursos para o Encoder. Neste caso, a função do Encoder foi implementada na função __loop__ principal do Arduino. 

O código a seguir conecta os botões Band, Step e Switch VFO/BFO às respectivas funções de tratamento (changeStep(), changeBand() e  switchVFOBFO()) 

```cpp
  // Will stop what Arduino is doing and call changeStep(), changeBand() or switchVFOBFO 
  attachInterrupt(digitalPinToInterrupt(BUTTON_STEP), changeStep, RISING);      // whenever the BUTTON_STEP goes from LOW to HIGH
  attachInterrupt(digitalPinToInterrupt(BUTTON_BAND), changeBand, RISING);      // whenever the BUTTON_BAND goes from LOW to HIGH
  attachInterrupt(digitalPinToInterrupt(BUTTON_VFO_BFO), switchVFOBFO, RISING); // whenever the BUTTON_VFO_BFO goes from LOW to HIGH
  // wait for 1/2 second and the system will be ready.
```

O código a seguir implementa de fato a função de cada botão. Observe também no código que a ação do botão só será executada se tiver decorrido um tempo mínimo após o último pressionamento (veja no programa a constante definida MIN_ELAPSED_TIME). Este artifício é utilizado porque o botão (Push Button) pode, em um único pressionamento, alterar mais de uma vez o status do pino que ele está conectado. Isso ocorre porque os contatos metálicos do botão não se comportam de forma tão precisa como aparentam. Diante disso, para que um único pressionamento do botão não seja entendido pelo sistema como vários, este recurso de medir o tempo decorrido após o último pressionamento, é utilizado. 

```cpp
// Change frequency increment rate
void changeStep()
{
  if ((millis() - elapsedTimeInterrupt) < MIN_ELAPSED_TIME)
    return;                                                            // nothing to do if the time less than MIN_ELAPSED_TIME milisecounds
  noInterrupts();                                                      //// disable global interrupts:
  if (currentClock == 0)                                               // Is VFO
    currentStep = (currentStep < lastStepVFO) ? (currentStep + 1) : 0; // Increment the step or go back to the first
  else                                                                 // Is BFO
    currentStep = (currentStep < lastStepBFO) ? (currentStep + 1) : 0;
  isFreqChanged = true;
  clearDisplay = true;
  elapsedTimeInterrupt = millis();
  interrupts(); // enable interrupts
}

// Change band
void changeBand()
{
  if ((millis() - elapsedTimeInterrupt) < MIN_ELAPSED_TIME)
    return;                                                       // nothing to do if the time less than 11 milisecounds
  noInterrupts();                                                 //  disable global interrupts:
  currentBand = (currentBand < lastBand) ? (currentBand + 1) : 0; // Is the last band? If so, go to the first band (AM). Else. Else, next band.
  vfoFreq = band[currentBand].minFreq;
  isFreqChanged = true;
  elapsedTimeInterrupt = millis();
  interrupts(); // enable interrupts
}

// Switch the Encoder control from VFO to BFO and virse versa.
void switchVFOBFO()
{
  if ((millis() - elapsedTimeInterrupt) < MIN_ELAPSED_TIME)
    return;       // nothing to do if the time less than 11 milisecounds
  noInterrupts(); //  disable global interrupts:
  currentClock = !currentClock;
  currentStep = 0; // go back to first Step (100Hz)
  clearDisplay = true;
  elapsedTimeInterrupt = millis();
  interrupts(); // enable interrupts
}
```

### Modificando o tipo de Display

Este projeto utiliza o "OLED Display Arduino 128 x 64 Pixels White 0.96 Inch I2C". Por ter um tamanho muito limitado, é possível que você queira trocar por um outro tipo de display. Para tanto, você deve conhecer bem como configurar e programar o seu display para o ambiente do Arduino. Uma vez decidido mudar o tipo de display, siga as orientações a seguir.

#### 1) Modifique a declaração da biblioteca para a do display que você utilizará

Observe as diretivas include a seguir e faça a substituição sugerida pelo fabricante do seu display. 

```cpp
#include "SSD1306Ascii.h"
#include "SSD1306AsciiAvrI2c.h"
```

#### 2) Declare a variável ou classe do seu display no programa Arduino 

Substitua a declaração da linha a seguir pela sugerida pelo fabricante do seu display. De preferência, mantanha o nome da variável __display__.

```cpp
// OLED - Declaration for a SSD1306 display connected to I2C (SDA, SCL pins)
SSD1306AsciiAvrI2c display;
```

#### 3) Altere o código de inicialização do display na função setup()

Substitua as linhas de código a seguir pela sugerida pelo fabricante do seu display.

```cpp
 // Initiating the OLED Display
  display.begin(&Adafruit128x64, I2C_ADDRESS);
  display.setFont(Adafruit5x7);
  display.set2X();
  display.clear();
  display.print("\n PU2CLR");
  delay(3000);
  display.clear();
  displayDial();
```

#### 4) Altere o códigoda função displayDial() pelo código adequado ao seu display  

O corpo da função display deve ser alterado de acordo com as funções utilizadas pelo seu display. Mantenha o nome da função __displayDial()__. 

```cpp
// Show Signal Generator Information
// Verificar setCursor() em https://github.com/greiman/SSD1306Ascii/issues/53
void displayDial()
{
  double vfo = vfoFreq / 100000.0;
  double bfo = bfoFreq / 100000.0;
  String mainFreq;
  String secoundFreq;
  String staticFreq;
  String dinamicFreq;

  // Change the display behaviour depending on who is controlled, BFO or BFO.
  if (currentClock == 0)
  { // If the encoder is controlling the VFO
    mainFreq = String(vfo,3);
    secoundFreq = String(bfo,3);
    staticFreq = "BFO";
    dinamicFreq = "VFO";
  }
  else // encoder is controlling the VFO
  {
    mainFreq = String(bfo,3);
    secoundFreq = String(vfo,3);
    staticFreq = "VFO";
    dinamicFreq = "BFO";
  }

  // display.setCursor(0,0)
  // display.clear();

  display.set2X();
  display.setCursor(0, 0);
  display.print(mainFreq);
  display.print("     ");

  display.set1X();
  display.print("\n\n\n");
  display.print(staticFreq);
  display.print(".: ");
  display.print(secoundFreq);

  display.print("\nBand: ");
  display.print(band[currentBand].name);

  display.print("\nStep: ");
  display.print(step[currentStep].name);

  display.print("\n\nCtrl: ");
  display.print(dinamicFreq);

}
```

## Considerações finais

O <a href="https://github.com/pu2clr/VFO_BFO_OLED_ARDUINO/blob/master/source/si5351_vfobfo.ino">código-fonte </a> deste projeto está com uma documentação bem rica que busca dirimir dúvidas quanto ao uso e configuração do Si5351, OLED Display, botões, Encoder e LED. A <a href="https://github.com/pu2clr/VFO_BFO_OLED_ARDUINO/issues">aba Issues</a>, logo acima desta página, poderá ser utilizado para a publicação de dúvidas ou defeitos encontrados neste projeto.    

## Fotos

#### Foto 01
 Foto do protótipo 1

#### Foto 02
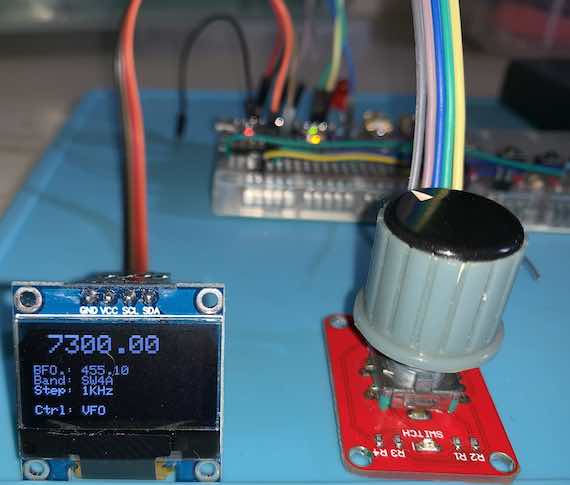
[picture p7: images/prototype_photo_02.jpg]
Foto do protótipo 2
 

#### Foto 03
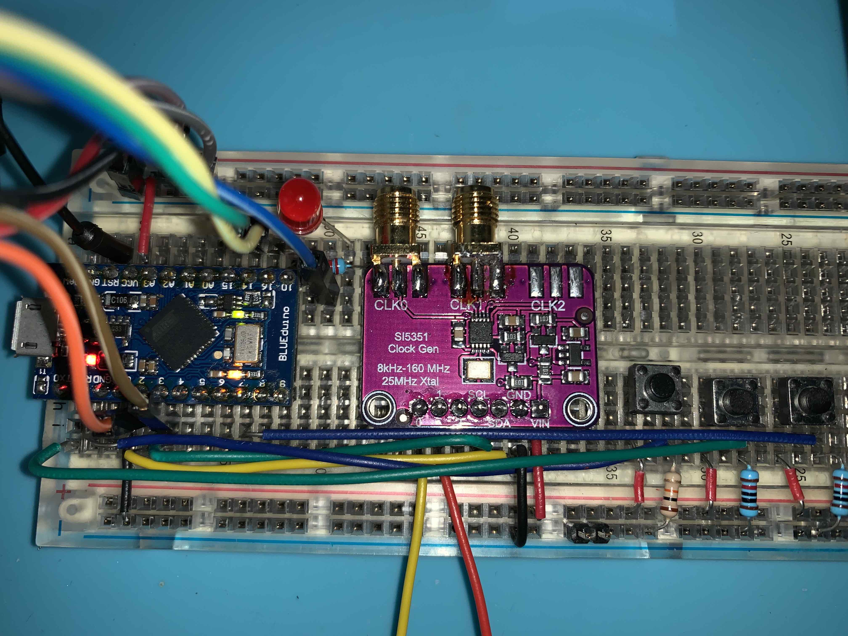
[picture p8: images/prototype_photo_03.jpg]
Foto do protótipo 3
 

## Referências

- [BFO Controlled by Arduino](https://github.com/pu2clr/BFO)
- [Arduino](https://www.arduino.cc)
- [Silicon Labs Si5351A/B/C-B](https://www.silabs.com/documents/public/data-sheets/Si5351-B.pdf)
- [Si5351 Library for Arduino](https://github.com/etherkit/Si5351Arduino)
- [All About Arduino Libraries](http://learn.adafruit.com/adafruit-all-about-arduino-libraries-install-use)
- [Arduino Wire Library](https://www.arduino.cc/en/Reference/Wire) 
- [Arduino - Usando Interrupções](https://www.arduino.cc/reference/pt/language/functions/external-interrupts/attachinterrupt/)
- [Tutorial: Arduino and the I2C bus – Part One](https://tronixstuff.com/2010/10/20/tutorial-arduino-and-the-i2c-bus/)
- [Adafruit Si5351A Clock Generator Breakout Board - 8KHz to 160MHz](https://www.adafruit.com/product/2045)
- [Arduino Frequency Synthesiser Using 160MHz Si5351, lingib](https://www.instructables.com/id/Arduino-Frequency-Synthesiser-Using-160MHz-Si5351/)
- [SI5351 Signal Generator](https://kk9jef.wordpress.com/2017/07/10/si5351-signal-generator/)
- [Arduino – Si5351 Powered Signal Generator, kk9jef](https://nt7s.com/2018/01/arduino-si5351-powered-signal-generator/) 
- [Text only Arduino Library for SSD1306 OLED displays](https://github.com/greiman/SSD1306Ascii)

## Vídeos

- [VFO and BFO with Si5351A controlled by Arduino, PU2CLR](https://youtu.be/pFDvcIk5EAk)
- [VFO e BFO com Si5351A e Arduino - Calibração do Si5351, PU2CLR](https://youtu.be/BJ83uvDcfIo)
- [VFO e BFO com o Si5351 e OLED controlado por Arduino - (Portuguese), PU2CLR](https://youtu.be/0sGL2KpOJH4)
- [NT7S Adafruit si5351 VFO/BFO](https://www.youtube.com/watch?v=791NupCbiWU)
- [Vídeo: Arduino Nano + Si5351 Three outputs HF VHF VFO](https://www.youtube.com/watch?v=xD6tLSOjSsw)
- [Simple vfo+bfo with s-meter using si5351 and arduino/avr](https://www.youtube.com/watch?v=s82TBVt3VG4&feature=youtu.be)
- [Homebrew HF transceiver with SI5351A](https://www.youtube.com/watch?v=JJ8-VEZk_28)
- [Arduino Signal Generator](https://www.youtube.com/watch?v=7M6ghR9tuTk)
- [Homebrew 80/40m SSB/CW Rig - #7a Si5351 Calibration](https://www.youtube.com/watch?v=fJ_3z2IAjKg)
- [Si5351 VFO/BFO Software: Part 1 Hardware overview](https://www.youtube.com/watch?v=58G5atwBX2M)
- [Bitx40 With an OLED Display and the Si5351](https://www.youtube.com/watch?v=VSPEC144A00&list=PLx2fI1IGczHx-p6aEuci4ETU4VM419cm_)
- [Arduino Tutorial: OLED 0.96" I2C/SPI Display](https://www.youtube.com/watch?v=PrIAnDZ9dp8)
- [Tutorial on I2C OLED Display with Arduino/NodeMCU](https://www.youtube.com/watch?v=_e_0HJY0uIo)
- [Arduino Tutorial: 0.96' 128x64 I2C OLED Display from banggood.com tutorial with review and drivers](https://www.youtube.com/watch?v=A9EwJ7M7OsI)
- [OLED Display I2C 128x64 With Arduino - Tutorial](https://www.youtube.com/watch?v=Iq9HHct6b9o)

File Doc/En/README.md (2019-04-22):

# VFO and BFO with Si5351A and Arduino project

## Table of contents

1. [Introduction](/Doc/En#introduction) 
1. [Arduino ATmega32U4](/Doc/En#arduino-atmega32u4)
1. [BFO interface](/Doc/En#vfo-and-bfo-interface)
	1. [VFO and BFO and Dial information](/Doc/En#vfo-and-bfo-and-dial-information)
1. [Band table for the VFO](/Doc/En#band-table-for-the-VFO)
1. [Schematic](/Doc/En#schematic)
1. [Components](/Doc/En#components)
1. [Arduino sketch](/Doc/En#arduino-sketch)
	1. [BFO range](/Doc/En#bfo-range)
	1. [Arduino pins and  Encoder, Band, Step and Switch VFO/BFO](/Doc/En#arduino-pins-and--encoder-band-step-and-switch-vfobfo)
	1. [Bands and frequency ranges](/Doc/En#bands-and-frequency-ranges)
	1. [External interrupts](/Doc/En#external-interrupts)
	1. [Changing the kind of display device](/Doc/En#changing-the-kind-of-display-device)
	1. [SI5351 Calibration](/Doc/En#sI5351-calibration)
1. [Photos](/Doc/En#photos)
1. [Expetiments and Applications](https://github.com/pu2clr/VFO_BFO_OLED_ARDUINO/tree/master/Experiments)
   1. [The BFO and VFO impplemented on Atmega328 (without use of external interruptions)](https://github.com/pu2clr/VFO_BFO_OLED_ARDUINO/tree/master/Experiments/Atmega328)  
   2. [IR Remote Control Implemetation for the VFO and BFO (Atmega328)](https://github.com/pu2clr/VFO_BFO_OLED_ARDUINO/tree/master/Experiments/IRController)
   3. [VFO and BFO project with a inexpencive radio based on CD2003GP](https://github.com/pu2clr/VFO_BFO_OLED_ARDUINO/tree/master/Experiments/VFO_RADIO_CD2003GP)
2. [References](/Doc/En#references)
3. [Videos](/Doc/En#videos)

## Introduction 

The Si5351 is an I2C configurable clock generator that is very appropriate for receivers and transceivers projects in amateur radio applications. It is also suited for replacing crystal oscillators. It has three outputs that you can get three distinct frequencies at the same time. A great feature of the Si5351A is the possibility of using it with a microcontroller or platform like Arduino, PIC family and others. See more on [Silicon Labs documentation](https://www.silabs.com/documents/public/data-sheets/Si5351-B.pdf)

 **This project is about a VFO and BFO that you can control two clock outputs of the Si5351A by using the Arduino Micro (Atmega32u4).  The VFO (CLK0) can oscillate from 100KHz to 160MHz and the second (CLK1) can oscillate from 452KHz to 458KHz**. 

The <a href="https://github.com/pu2clr/VFO_BFO_OLED_ARDUINO/blob/master/source/si5351_vfobfo.ino"> Arduino program </a> has being documented in English lenguage and you can get more details about the Si5351A controls by reading the <a href="https://github.com/pu2clr/VFO_BFO_OLED_ARDUINO/blob/master/source/si5351_vfobfo.ino">si5351_vfobfo.ino file</a>. 

## Arduino ATmega32U4

This project uses the Arduino ATmega32U4 (Known as Arduino Micro) with a built-in USB.  The ATmega32U4 has 5 pins (0,1,2, 3 and 7) that allow the developer to use for handling external interrupts. This feature is very useful in this project. See more about Arduino Micro (ATmega32U4) <a href="https://store.arduino.cc/usa/arduino-micro">here</a>.

## VFO and BFO interface

The user can control the VFO and BFO by using three buttons and an encoder. The Dial was implemented with the OLED Display 128 x 64 Pixels White 0.96 Inch I2C. 

- The button __Band__ changes the range of frequency. This project divides the VFO range (from 100KHz to 160MHz) in 27 bands. See band table below;  
- The button __Step__ changes the increment and decrement step. It can be 10Hz, 50Hz, 100Hz, 500Hz, 1KHz, 2.5KHz, 5KHz, 10KHz, 100KHz and 500KHz;
- The button __VFO/BFO__ switches from VFO to BFO and vice-versa. It allows the user to control the VFO or BFO by using the same __Encoder__;
- The __Encoder__ is used to increment or decrement the current frequency by using the step value as a
	reference.

### VFO and BFO and Dial information

The Dial shows the current VFO and BFO frequencies, the step and who the encoder is controlling (VFO or BFO).
When the user switch from VFO to BFO or vice-versa, the frequency information of the VFO or BFO is highlighted on display.
If you want to use another display, the item [Arduino sketch](/Doc/En#arduino-sketch) ([Changing the kind of display device](/Doc/En#changing-the-kind-of-display-device)) shows how you can do that. 

|  Dial Information | Dial Information |
| --- | --- |
| Photo dial 01|  Photo dial 02 |
| VFO is 100 KHz, BFO is 455 KHz, Band LW/MW, 10Hz setp and the encoder is controlling the VFO)| The encoder is controlling the BFO; the BFO now is the first information (highlighted)| 
| Photo dial 03|  Photo dial 04 |
| VFO is 1700.08 KHz, BFO is 455 KHz, Band SW1, 10Hz setp and the encoder is controllins the VFO)| VFO is 108MHz, BFO is 455 KHz, Band VFH4, 2.5KHz setp and the encoder is controllins the VFO) | 

## Band table for the VFO

The VFO is separated into 27 bands. It first band oscilates from 100KHz to 1700 KHz and the last band oscilates from 135MHz to 160MHz. You might need to change this configuration. The [Arduino sketch](/Doc/En#arduino-sketch) ([Bands and frequency ranges](/Doc/En#bands-and-frequency-ranges)) shows how you can change the band configuration. 

<table cellspacing="0" border="0">
	<colgroup width="37"></colgroup>
	<colgroup width="91"></colgroup>
	<colgroup width="106"></colgroup>
	<colgroup width="111"></colgroup>
	<colgroup width="115"></colgroup>
	<tr>
		<td height="23" align="left">N#</td>
		<td align="left">Band</td>
		<td align="left">From</td>
		<td align="left">to</td>
	</tr>
	<tr>
		<td height="23" align="right" sdval="1" sdnum="1046;">1</td>
		<td align="left">LW/MW </td>
		<td align="left"> 100 KHz</td>
		<td align="left"> 1.7 MHz</td>
	</tr>
	<tr>
		<td height="23" align="right" sdval="2" sdnum="1046;">2</td>
		<td align="left">SW1  </td>
		<td align="left"> 1.7 MHz</td>
		<td align="left"> 3.5 MHz</td>
	</tr>
	<tr>
		<td height="23" align="right" sdval="3" sdnum="1046;">3</td>
		<td align="left">SW2  </td>
		<td align="left"> 3.5 MHz</td>
		<td align="left"> 4.0 MHz</td>
 	</tr>
	<tr>
		<td height="23" align="right" sdval="4" sdnum="1046;">4</td>
		<td align="left">SW3  </td>
		<td align="left"> 4.0 MHz</td>
		<td align="left"> 7.0 MHz</td>
 	</tr>
	<tr>
		<td height="23" align="right" sdval="5" sdnum="1046;">5</td>
		<td align="left">SW4  </td>
		<td align="left"> 7.0 MHz</td>
		<td align="left"> 7.3 MHz</td>
 	</tr>
	<tr>
		<td height="23" align="right" sdval="6" sdnum="1046;">6</td>
		<td align="left">SW5  </td>
		<td align="left"> 7.3 MHz</td>
		<td align="left"> 9.0 MHz</td>
 	</tr>
	<tr>
		<td height="23" align="right" sdval="7" sdnum="1046;">7</td>
		<td align="left">SW6  </td>
		<td align="left"> 9.0 MHz</td>
		<td align="left"> 10.0 MHz</td>
 	</tr>
	<tr>
		<td height="23" align="right" sdval="8" sdnum="1046;">8</td>
		<td align="left">SW7  </td>
		<td align="left"> 10.0 MHz</td>
		<td align="left"> 11.0 MHz</td>
 	</tr>
	<tr>
		<td height="23" align="right" sdval="9" sdnum="1046;">9</td>
		<td align="left">SW8  </td>
		<td align="left"> 11.0 MHz</td>
		<td align="left"> 14.0 MHz</td>
 	</tr>
	<tr>
		<td height="23" align="right" sdval="10" sdnum="1046;">10</td>
		<td align="left">SW9  </td>
		<td align="left"> 14.0 Mhz</td>
		<td align="left"> 15.0 MHz</td>
 	</tr>
	<tr>
		<td height="23" align="right" sdval="11" sdnum="1046;">11</td>
		<td align="left">SW10 </td>
		<td align="left"> 15.0 MHz</td>
		<td align="left"> 17.0 MHz</td>
 	</tr>
	<tr>
		<td height="23" align="right" sdval="12" sdnum="1046;">12</td>
		<td align="left">SW11 </td>
		<td align="left"> 17.0 MHz</td>
		<td align="left"> 18.0 MHz</td>
 	</tr>
	<tr>
		<td height="23" align="right" sdval="13" sdnum="1046;">13</td>
		<td align="left">SW12 </td>
		<td align="left"> 18.0 MHz</td>
		<td align="left"> 20.0 MHz</td>
 	</tr>
	<tr>
		<td height="23" align="right" sdval="14" sdnum="1046;">14</td>
		<td align="left">SW13 </td>
		<td align="left"> 20.0 MHz</td>
		<td align="left"> 21.35 MHz</td>
 	</tr>
	<tr>
		<td height="23" align="right" sdval="15" sdnum="1046;">15</td>
		<td align="left">SW14 </td>
		<td align="left"> 21.35 MHz</td>
		<td align="left">22.00 MHz</td>
 	</tr>
	<tr>
		<td height="23" align="right" sdval="16" sdnum="1046;">16</td>
		<td align="left">SW15 </td>
		<td align="left"> 22.0 MHz</td>
		<td align="left"> 24.88 MHz</td>
 	</tr>
	<tr>
		<td height="23" align="right" sdval="17" sdnum="1046;">17</td>
		<td align="left">SW16 </td>
		<td align="left"> 24.88 MHz</td>
		<td align="left"> 24.99 MHz</td>
 	</tr>
	<tr>
		<td height="23" align="right" sdval="18" sdnum="1046;">18</td>
		<td align="left">SW17 </td>
		<td align="left"> 24.99 MHz</td>
		<td align="left"> 26.0 MHz</td>
 	</tr>
	<tr>
		<td height="23" align="right" sdval="19" sdnum="1046;">19</td>
		<td align="left">SW18 </td>
		<td align="left"> 26.0 MHz</td>
		<td align="left"> 28.0 MHz</td>
 	</tr>
	<tr>
		<td height="23" align="right" sdval="20" sdnum="1046;">20</td>
		<td align="left">SW19 </td>
		<td align="left"> 28.0 MHz</td>
		<td align="left"> 30.0 MHz</td>
 	</tr>
	<tr>
		<td height="23" align="right" sdval="21" sdnum="1046;">21</td>
		<td align="left">VHF1 </td>
		<td align="left"> 30.0 MHz</td>
		<td align="left"> 50.0 MHz</td>
 	</tr>
	<tr>
		<td height="23" align="right" sdval="22" sdnum="1046;">22</td>
		<td align="left">VHF2 </td>
		<td align="left"> 50.0 MHz</td>
		<td align="left"> 54.0 MHz</td>
 	</tr>
	<tr>
		<td height="23" align="right" sdval="23" sdnum="1046;">23</td>
		<td align="left">VHF3 </td>
		<td align="left"> 54.0 MHz</td>
		<td align="left"> 86.0 MHz</td>
 	</tr>
	<tr>
		<td height="23" align="right" sdval="24" sdnum="1046;">24</td>
		<td align="left">FM   </td>
		<td align="left"> 86.0 MHz</td>
		<td align="left"> 108.0 MHz</td>
 	</tr>
	<tr>
		<td height="23" align="right" sdval="25" sdnum="1046;">25</td>
		<td align="left">VHF4 </td>
		<td align="left"> 108.0 MHz</td>
		<td align="left"> 120.0 MHz </td>
 	</tr>
	<tr>
		<td height="23" align="right" sdval="26" sdnum="1046;">26</td>
		<td align="left">VHF5 </td>
		<td align="left"> 120.0 MHz</td>
		<td align="left"> 135.0 MHz</td>
 	</tr>
	<tr>
		<td height="23" align="right" sdval="27" sdnum="1046;">27</td>
		<td align="left">VHF6 </td>
		<td align="left"> 135.0 MHz</td>
		<td align="left"> 160.0 MHz</td>
 	</tr>
</table> 

## Schematic

The schematic was built using the [Fritzing](http://fritzing.org/home/) application, an open-source software tools to design circuits. The schematic below shows the Arduino and components wire up.

 Esquema do Projeto VFO e BFO com Arduino

## Components

- AZDelivery 1 x OLED Display Arduino 128 x 64 Pixels White 0.96 Inch I2C IIC Module for Arduino. This project uses the [Text only Arduino Library for SSD1306 OLED displays](https://github.com/greiman/SSD1306Ascii) Arduino library.
- Adafruit Si5351A Clock Generator Breakout Board - 8KHz to 160MHz. This project uses the [Si5351 Library for Arduino](https://github.com/etherkit/Si5351Arduino).
- One regular encoder.
- Three regular Push Button.
- Two 10nF ceramic capacitor
- Six 10K resistor
- One 1K resistor  
- One Red LED
- Arduino Micro ([Atmega32u4](https://www.microchip.com/wwwproducts/en/ATmega32u4))

### About schematic and connections

This project uses the Arduino Atmega32u4 compatible (Micro). With this kind of Arduino, we can use up to 5 external interrupts (pins 0,1,2,3 and 7). Then pins 0,1 and 7 were used to implement the buttons command (Step, Band and switch VFO/BFO).

#### Si5351A

The device Si5351A is connected to pins D2 (SDA) and D3 (SCL).  

#### OLED Display SSD1306 - 128 x 64/0.96

The OLED Display is also connected to D2(SDA) and D3 (SCL).  

#### Encoder
The Encoder is connected to Arduino on pins D8 and D9. Connect the lead A to pin D8 and lead B to pin D9. 

#### Band push button

The Band push button is connected to pin D0/Rx (see schematic). Use this button to select one of 27 bands available.   

#### Step push button

The Step push button is connected to the pin D1/Tx. Use this button to select the increment and decrement frequency steps.   

#### VFO/BFO switch

The VFO/BFO switch push button is connected to the pin D7.   This button changes the Encoder control from VFO to BFO and vice versa.  

## Arduino sketch 

The main Arduino library used on this project to control the Si5351A was developed by NTS7. You can see more about this Library <a href="https://github.com/etherkit/Si5351Arduino">here</a>. 

#### BFO range

If you want to modify the frequency of BFO to 10MHz (for example), just change the lines below. 

```cpp
#define MAX_BFO     1100000000LU   // BFO max. frequency 
#define CENTER_BFO  1000000000LU   // BFO center frequency
#define MIN_BFO      990000000LU   // BFO min. frequency 
```

#### Bands and frequency ranges

The bands and ranges can be changed here. You can remove band and change frequencies modifying the array band[]. See code below. 

```cpp
// Band database. You can change the band ranges if you need.
Band band[] = {
    {"LW/MW ", 10000000LLU, 170000000LLU},     // 100KHz to 1700KHz
    {"SW1  ", 170000000LLU, 350000000LLU},
    {"SW2  ", 350000000LLU, 400000001LLU},
    {"SW3  ", 400000000LLU, 700000000LLU},
    {"SW4  ", 700000000LLU, 730000000LLU},    // 7MHz to 7.3 MHz  (Amateur 40m)
    {"SW5  ", 730000000LLU, 900000000LLU},    // 41m
    {"SW6  ", 900000000LLU, 1000000000LLU},   // 31m
    {"SW7  ", 1000000000LLU, 1100000000LLU},  // 10 MHz to 11 MHz (Amateur 30m)
    {"SW8  ", 1100000000LLU, 1400000000LLU},  // 25 and 22 meters
    {"SW9  ", 1400000000LLU, 1500000000LLU},  // 14MHz to 15Mhz (Amateur 20m)
    {"SW10 ", 1500000000LLU, 1700000000LLU},  // 19m
    {"SW11 ", 1700000000LLU, 1800000000LLU},  // 16m
    {"SW12 ", 1800000000LLU, 2000000000LLU}, // 18MHz to 20Mhz (Amateur and comercial 15m)
    {"SW13 ", 2000000000LLU, 2135000000LLU}, // 20MHz to 22Mhz (Amateur and comercial 15m/13m)
    {"SW14 ", 2135000000LLU, 2200000000LLU},
    {"SW15 ", 2235000000LLU, 2498000000LLU},
    {"SW16 ", 2488000000LLU, 2499000000LLU}, // 24.88MHz to 24.99MHz (Amateur 12m)
    {"SW17 ", 2499000000LLU, 2600000000LLU},
    {"SW18 ", 2600000000LLU, 2800000000LLU},
    {"SW19 ", 2800000000LLU, 3000000000LLU}, // 28MHz to 30MHz (Amateur 10M)
    {"VHF1 ", 3000000000LLU, 5000000000LLU},
    {"VHF2 ", 5000000000LLU, 5400000000LLU},
    {"VHF3 ", 5400000000LLU, 8600000000LLU},
    {"FM   ", 8600000000LLU, 10800000000LLU},  // Comercial FM
    {"VHF4 ", 10800000000LLU, 12000000000LLU}, // 108MHz to 160MHz
    {"VHF5 ", 12000000000LLU, 13500000000LLU},
    {"VHF6 ", 13500000000LLU, 16000000000LLU}}; 
// Calculate the last element position (index) of the array band 
const int lastBand = (sizeof band / sizeof(Band)) - 1; // For this case will be 26.
volatile int currentBand = 0; // First band. For this case, AM is the current band.	
```

#### The increment and decrement steps can be changed here.

The steps of BFO can be changed here. 

```cpp
// Steps database. You can change the Steps and numbers of steps here if you need.
Step step[] = {
    {"10Hz  ", 1000}, // VFO and BFO min. increment / decrement
    {"50Hz  ", 5000},
    {"100Hz ", 10000},
    {"500Hz ", 50000},
    {"1KHz  ", 100000}, // BFO max. increment / decrement
    {"2.5KHz", 250000},
    {"5KHz  ", 500000},
    {"10KHz ", 1000000},
    {"100KHz", 10000000},
    {"500KHz", 50000000}}; // VFO max. increment / decrement
// Calculate the index of last position of step[] array (in this case will be 8)
const int lastStepVFO = (sizeof step / sizeof(Step)) - 1; // index for max increment / decrement for VFO
volatile int lastStepBFO = 3;   // index for max. increment / decrement for BFO. In this case will be is 1KHz
volatile long currentStep = 0;  // it stores the current step index (50Hz in this case)
```

### Arduino pins and  Encoder, Band, Step and Switch VFO/BFO

The pins for encoder and push buttons are defined below. If you need to change some push button pin, you should be aware that the push buttons are connected to  pins with support to external interrupts. On Atmega32u4 you can use the pins 0,1,2,3 and 7.

```cpp
#define ENCODER_PIN_A 8 // Arduino  D8
#define ENCODER_PIN_B 9 // Arduino  D9

#define BUTTON_STEP 0    // Control the frequency increment and decrement
#define BUTTON_BAND 1    // Controls the band
#define BUTTON_VFO_BFO 7 // Switch VFO to BFO
```

### External interrupts

The Band, Step and Switch VFO/BFO buttons are implemented by using external interrupt resource. 
[See more about Using Interrupts on Arduino.](https://www.arduino.cc/reference/en/language/functions/external-interrupts/attachinterrupt/)

```cpp
  // Will stop what Arduino is doing and call changeStep(), changeBand() or switchVFOBFO 
  attachInterrupt(digitalPinToInterrupt(BUTTON_STEP), changeStep, RISING);      // whenever the BUTTON_STEP goes from LOW to HIGH
  attachInterrupt(digitalPinToInterrupt(BUTTON_BAND), changeBand, RISING);      // whenever the BUTTON_BAND goes from LOW to HIGH
  attachInterrupt(digitalPinToInterrupt(BUTTON_VFO_BFO), switchVFOBFO, RISING); // whenever the BUTTON_VFO_BFO goes from LOW to HIGH
  // wait for 1/2 second and the system will be ready.
```

The changeStep(), changeBand() and switchVFOBFO() functions implementation are shown below. 

```cpp
// Change frequency increment rate
void changeStep()
{
  if ((millis() - elapsedTimeInterrupt) < MIN_ELAPSED_TIME)
    return;                                                            // nothing to do if the time less than MIN_ELAPSED_TIME milisecounds
  noInterrupts();                                                      //// disable global interrupts:
  if (currentClock == 0)                                               // Is VFO
    currentStep = (currentStep < lastStepVFO) ? (currentStep + 1) : 0; // Increment the step or go back to the first
  else                                                                 // Is BFO
    currentStep = (currentStep < lastStepBFO) ? (currentStep + 1) : 0;
  isFreqChanged = true;
  clearDisplay = true;
  elapsedTimeInterrupt = millis();
  interrupts(); // enable interrupts
}

// Change band
void changeBand()
{
  if ((millis() - elapsedTimeInterrupt) < MIN_ELAPSED_TIME)
    return;                                                       // nothing to do if the time less than 11 milisecounds
  noInterrupts();                                                 //  disable global interrupts:
  currentBand = (currentBand < lastBand) ? (currentBand + 1) : 0; // Is the last band? If so, go to the first band (AM). Else. Else, next band.
  vfoFreq = band[currentBand].minFreq;
  isFreqChanged = true;
  elapsedTimeInterrupt = millis();
  interrupts(); // enable interrupts
}

// Switch the Encoder control from VFO to BFO and virse versa.
void switchVFOBFO()
{
  if ((millis() - elapsedTimeInterrupt) < MIN_ELAPSED_TIME)
    return;       // nothing to do if the time less than 11 milisecounds
  noInterrupts(); //  disable global interrupts:
  currentClock = !currentClock;
  currentStep = 0; // go back to first Step (100Hz)
  clearDisplay = true;
  elapsedTimeInterrupt = millis();
  interrupts(); // enable interrupts
}
```

### Changing the kind of display device

This project uses the "OLED Display Arduino 128 x 64 Pixels White 0.96 Inch I2C". It is very small and does not provide a good look. If you need to change to a larger display device, you have to know how to connect your display device on your Arduino. Also you have to know how to program your display device for Arduino. If you are able to do that, you can follow the steps bellow. 

#### 1) Replacing the libraries declaration

Replace the OLED library include directives below by the library include directive of your device display.

```cpp
#include "SSD1306Ascii.h"
#include "SSD1306AsciiAvrI2c.h"
```

#### 2) Replacing the display device class declaration 

Replace the OLED display declaration by your display device declaration

```cpp
// OLED - Declaration for a SSD1306 display connected to I2C (SDA, SCL pins)
SSD1306AsciiAvrI2c display;
```

#### 3) Replacing the OLED display device initialization code

Replace the OLED display device initialization code on setup() function by the your display device initialization code.

```cpp
 // Initiating the OLED Display
  display.begin(&Adafruit128x64, I2C_ADDRESS);
  display.setFont(Adafruit5x7);
  display.set2X();
  display.clear();
  display.print("\n PU2CLR");
  delay(3000);
  display.clear();
  displayDial();
```

#### 4) Replacing the OLED displayDial() function  

Replace the displayDial function code by the your display device code. Keep the name of the function (diaplayDial()).

```cpp
// Show Signal Generator Information
// Verificar setCursor() em https://github.com/greiman/SSD1306Ascii/issues/53
void displayDial()
{
  double vfo = vfoFreq / 100000.0;
  double bfo = bfoFreq / 100000.0;
  String mainFreq;
  String secoundFreq;
  String staticFreq;
  String dinamicFreq;

  // Change the display behaviour depending on who is controlled, BFO or BFO.
  if (currentClock == 0)
  { // If the encoder is controlling the VFO
    mainFreq = String(vfo,3);
    secoundFreq = String(bfo,3);
    staticFreq = "BFO";
    dinamicFreq = "VFO";
  }
  else // encoder is controlling the VFO
  {
    mainFreq = String(bfo,3);
    secoundFreq = String(vfo,3);
    staticFreq = "VFO";
    dinamicFreq = "BFO";
  }

  // display.setCursor(0,0)
  // display.clear();

  display.set2X();
  display.setCursor(0, 0);
  display.print(mainFreq);
  display.print("     ");

  display.set1X();
  display.print("\n\n\n");
  display.print(staticFreq);
  display.print(".: ");
  display.print(secoundFreq);

  display.print("\nBand: ");
  display.print(band[currentBand].name);

  display.print("\nStep: ");
  display.print(step[currentStep].name);

  display.print("\n\nCtrl: ");
  display.print(dinamicFreq);

}
```

### SI5351 Calibration

You might need calibrate your si5351 to get more precision during signal generation. To do that you can use the si5351_calibration.ino sketch that comes with [the Si5351 library for Arduino](https://github.com/etherkit/Si5351Arduino). Click [here](https://github.com/etherkit/Si5351Arduino#calibration) to see more about si5351 calibration. You can also try watch [this Portuguese video](https://youtu.be/BJ83uvDcfIo) that show how to calibrate the si5351. Another video about si5351 calibration can be watch [here (Homebrew 80/40m SSB/CW Rig - #7a Si5351 Calibration)](https://youtu.be/fJ_3z2IAjKg).

The line code below shows the correction factor found during this project. 

```cpp
// Change this value below  (CORRECTION_FACTOR) to 0 if you do not know the correction factor of your Si5351A.
#define CORRECTION_FACTOR 80000 // See how to calibrate your Si5351A (0 if you do not want).
```

if you do not want calibrate, set CORRECTION_FACTOR to 0 as shown below. 

```cpp
#define CORRECTION_FACTOR 0 
```

## Photos

#### Photo 01
 Prototype01

#### Photo 02
 Prototype02

#### Photo 03
 Prototype03

## References

- [BFO Controlled by Arduino](https://github.com/pu2clr/BFO)
- [Arduino](https://www.arduino.cc)
- [Arduino Micro Pinout](http://pinoutguide.com/Electronics/arduino_micro_pinout.shtml)
- [Atmega32u4](https://www.microchip.com/wwwproducts/en/ATmega32u4)
- [Arduino Interrupts](https://www.arduino.cc/reference/en/language/functions/interrupts/interrupts/)
- [All About Arduino Libraries](http://learn.adafruit.com/adafruit-all-about-arduino-libraries-install-use)
- [Tutorial: Arduino and the I2C bus – Part One](https://tronixstuff.com/2010/10/20/tutorial-arduino-and-the-i2c-bus/)
- [Arduino Frequency Synthesiser Using 160MHz Si5351, lingib](https://www.instructables.com/id/Arduino-Frequency-Synthesiser-Using-160MHz-Si5351/)
- [Text only Arduino Library for SSD1306 OLED displays](https://github.com/greiman/SSD1306Ascii)
- [Si5351 Library for Arduino](https://github.com/etherkit/Si5351Arduino)
- [Si5351 calibration](https://github.com/etherkit/Si5351Arduino#calibration)
- [Silicon Labs Si5351A/B/C-B](https://www.silabs.com/documents/public/data-sheets/Si5351-B.pdf)
- [Fritzing](http://fritzing.org/home/)
- [My ham radio Facebook](https://www.facebook.com/PU2CLR)
- [QRZ - Biografy and my ham radio page](https://www.qrz.com/db/PU2CLR)

## Videos

- [BFO with SI5351 and Arduino test with REDSUN RP2100](https://youtu.be/AG9XZ8bdaNM)
- [VFO and BFO with Si5351A controlled by Arduino](https://youtu.be/pFDvcIk5EAk)
- [VFO e BFO com Si5351A e Arduino - Calibração do Si5351](https://youtu.be/BJ83uvDcfIo)
- [VFO e BFO com o Si5351 e OLED controlado por Arduino - (Portuguese)](https://youtu.be/0sGL2KpOJH4)
- [Homebrew 80/40m SSB/CW Rig - #7a Si5351 Calibration](https://youtu.be/fJ_3z2IAjKg)
- [Arduino Signal Generator](https://www.youtube.com/watch?v=7M6ghR9tuTk)
- [Arduino Tutorial: OLED 0.96" I2C/SPI Display](https://www.youtube.com/watch?v=PrIAnDZ9dp8)
- [Tutorial on I2C OLED Display with Arduino/NodeMCU](https://www.youtube.com/watch?v=_e_0HJY0uIo)
- [1.7inch 160x128 Color OLED(NHD-1.69-160128UGC3)](https://youtu.be/HjzTwqTvjqQ)
- [si5351 VFO with adaptive step control bulit by JF3HZB](https://youtu.be/ZkfQFdTcnG8)
- [Frequency Counter](https://youtu.be/e92y0ONECDc)
- [VFO Universal protótipo](https://youtu.be/XlEouO-2E3s)

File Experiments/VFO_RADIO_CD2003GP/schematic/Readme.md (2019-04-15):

# The Arduino and components wire up.

This schematic was made by using the [Fritzing Software](http://fritzing.org/home/)">

## Schematic

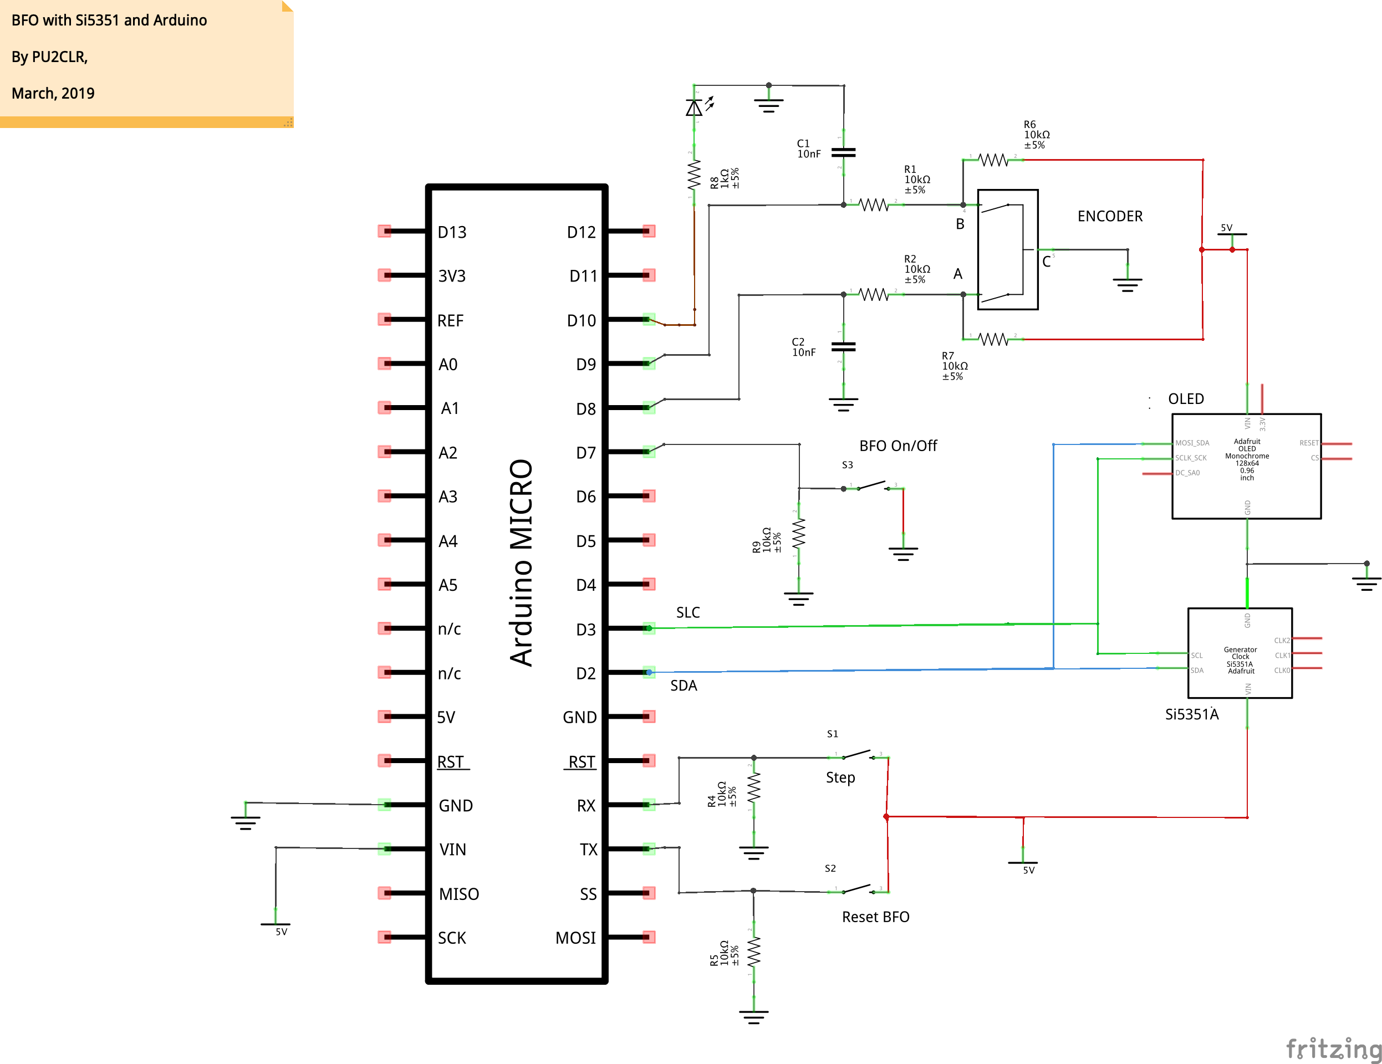
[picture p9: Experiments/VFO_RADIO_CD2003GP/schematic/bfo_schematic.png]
BFO schematic
 

### Si5351A

The __Si5351A__ is connected to D2 (SDA) and  D3 (SCL).

### OLED Display SSD1306 - 128 x 64/0.96

The __OLED__ is connected to D2 (SDA) and  D3 (SCL). Yes, the same Si5351A connections.

### Encoder

Connect Arduino __D8__ and __D9__ pins to the __Encoder__ pin __A__ and pin __B__ respectively.

### Push Button Step

Connect Arduino __D1/Tx__ pin to the __Step__ push button (S1). 

### Reset VFO

Connect Arduino __D0__ pin to the __Reset BFO__ push button (S2).

### BFO On/OFF 

Connect the Arduino pin __D7__ to the BFO On/Off push button  (S3).

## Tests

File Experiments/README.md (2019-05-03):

# Expetiments and Applications with VFO and BFO controlled by Arduino

This folder contains some tests, experimentations and applications with the VFO and BFO based on si5351 controlled by Arduino.

- [Atmega328](https://github.com/pu2clr/VFO_BFO_OLED_ARDUINO/tree/master/Experiments/Atmega328) - This folder has a version of he VFO and BFO based on si5351 controlled by Arduino based on Atmega328 (UNO, Mini, NAO etc);
 - [IRCOntrolle](https://github.com/pu2clr/VFO_BFO_OLED_ARDUINO/tree/master/Experiments/IRController) -  This folder has a version of the VFO and BFO working with IR remote control;
 - [VFO_RADIO_CD2003GP](https://github.com/pu2clr/VFO_BFO_OLED_ARDUINO/tree/master/Experiments/VFO_RADIO_CD2003GP) -  This folder has an application of the VFO and BFO project with a inexpencive radio based on CD2003GP chip. A $6 comercial radio was modified to be tuned by the VFO with si5351 controlled by Arduino.
  - [VFO Mobile Remote Control for iPhone and Android](https://github.com/pu2clr/VFO_BFO_OLED_ARDUINO/tree/master/Experiments/VFO_RADIO_CD2003GP/source/vfoMobileApplication) - It is a mobile apllication that comunicate with VFO vi Bluetooth (BLE).

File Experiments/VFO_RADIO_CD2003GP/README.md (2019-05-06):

# VFO and BFO project test with an inexpencive radio based on CD2003GP 

## __Documentação em Português clique [aqui](https://github.com/pu2clr/VFO_BFO_OLED_ARDUINO/tree/master/Experiments/VFO_RADIO_CD2003GP/Docs).__

By PU2CLR - Ricardo
April, 2019

## Table of contents

1. [Introduction](https://github.com/pu2clr/VFO_BFO_OLED_ARDUINO/tree/master/Experiments/VFO_RADIO_CD2003GP#introduction)
2. [Display layout](https://github.com/pu2clr/VFO_BFO_OLED_ARDUINO/tree/master/Experiments/VFO_RADIO_CD2003GP#display-layout)
3. [Schematic used with Arduino Atmega328 (UNO, Pro Mini, Nano etc)](https://github.com/pu2clr/VFO_BFO_OLED_ARDUINO/tree/master/Experiments/VFO_RADIO_CD2003GP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)
4. [Schematic used with Arduino ATmega32U4 (Micro)](https://github.com/pu2clr/VFO_BFO_OLED_ARDUINO/tree/master/Experiments/VFO_RADIO_CD2003GP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)
5. [Radio based on CD2003GP](https://github.com/pu2clr/VFO_BFO_OLED_ARDUINO/tree/master/Experiments/VFO_RADIO_CD2003GP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)
6. [Arduino Sketch](https://github.com/pu2clr/VFO_BFO_OLED_ARDUINO/tree/master/Experiments/VFO_RADIO_CD2003GP#arduino-sketch)
7. [Step Table](https://github.com/pu2clr/VFO_BFO_OLED_ARDUINO/tree/master/Experiments/VFO_RADIO_CD2003GP#step-table)
8. [Source folder](https://github.com/pu2clr/VFO_BFO_OLED_ARDUINO/tree/master/Experiments/VFO_RADIO_CD2003GP/source)
   1. [Arduino sketch for Atmega328 - si5351_vfoCD2003GP_atmega328.ino](https://github.com/pu2clr/VFO_BFO_OLED_ARDUINO/tree/master/Experiments/VFO_RADIO_CD2003GP/source/si5351_vfoCD2003GP_atmega328)
   2. [Arduino sketch for Atmega32U4 - si5351_vfoCD2003GP_atmega32u4.ino](https://github.com/pu2clr/VFO_BFO_OLED_ARDUINO/tree/master/Experiments/VFO_RADIO_CD2003GP/source/si5351_vfoCD2003GP_atmega32u4) 
   3. [Arduino sketch Atmega 328 and Bluetooth BLE-HM10 - si5351_vfo_ble_atmega328.ino](https://github.com/pu2clr/VFO_BFO_OLED_ARDUINO/tree/master/Experiments/VFO_RADIO_CD2003GP/source/si5351_vfo_ble_atmega328)
   4. [Remote control Mobile Application for Android and iOS](https://github.com/pu2clr/VFO_BFO_OLED_ARDUINO/tree/master/Experiments/VFO_RADIO_CD2003GP/source/vfoMobileApplication)
9. [Videos](https://github.com/pu2clr/VFO_BFO_OLED_ARDUINO/tree/master/Experiments/VFO_RADIO_CD2003GP#v%C3%ADdeos)

## Introduction

This folder has an example of using the VFO and BFO project with an inexpencive radio based on CD2003GP chip. A $6 commercial radio for receiving AM/FM broadcast was modified to be tuned by the VFO with si5351 controlled by Arduino. This experiment uses just the FM feature of the radio. 

The original Arduino sketch was modified to make make this experiment easyest. See below.

- The layout of the OLED display was adjusted 
- The amount of bands was reduced from 27 to 8. See [Band table below](https://github.com/pu2clr/VFO_BFO_OLED_ARDUINO/tree/master/Experiments/VFO_RADIO_CD2003GP#band-table)
- Each band has a different behavior. That is, frequency unit shown on the display and steps more suitable for the specific band. See [Band table below](https://github.com/pu2clr/VFO_BFO_OLED_ARDUINO/tree/master/Experiments/VFO_RADIO_CD2003GP#band-table)

### Display Layout

| Layout |  Layout |
| --- |  --- |
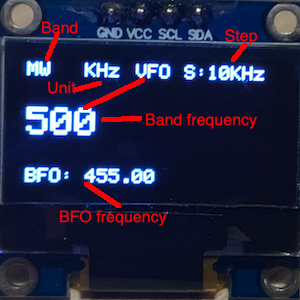
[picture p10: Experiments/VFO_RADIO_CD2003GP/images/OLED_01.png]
Displau photo 1
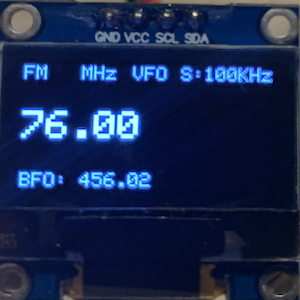
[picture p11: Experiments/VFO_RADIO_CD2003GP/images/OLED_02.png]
Displau photo 2
| |  |
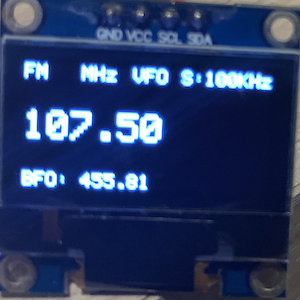
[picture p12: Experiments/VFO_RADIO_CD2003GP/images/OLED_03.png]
Displau photo 3
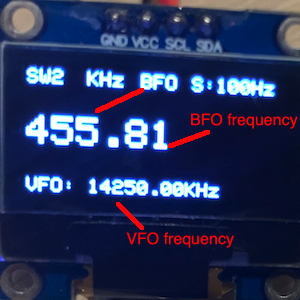
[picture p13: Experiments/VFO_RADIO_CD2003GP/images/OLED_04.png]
Displau photo 4
| |  |

## Schematic used with Arduino Atmega328 (UNO, Pro Mini, Nano etc)

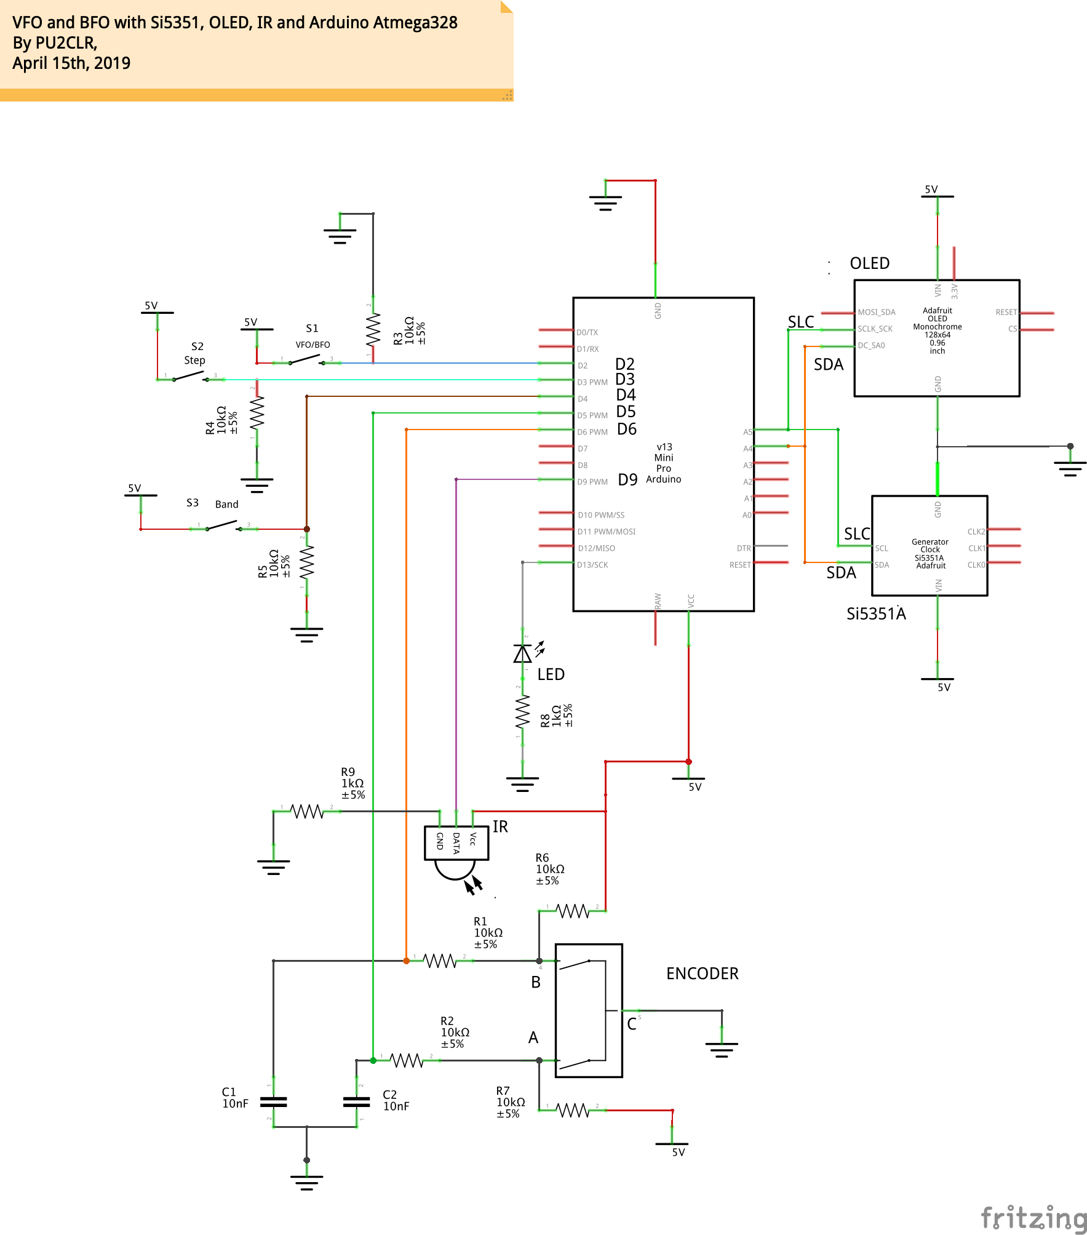
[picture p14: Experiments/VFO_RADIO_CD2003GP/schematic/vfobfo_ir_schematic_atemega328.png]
Schematic used with Arduino Atmega328


__Click [here](https://github.com/pu2clr/VFO_BFO_OLED_ARDUINO/blob/master/Experiments/VFO_RADIO_CD2003GP/source/si5351_vfoCD2003GP_atmega328/si5351_vfoCD2003GP_atmega328.ino) to see the sketch used on Arduino Atmega328 (schematic above).__

## Schematic used with Arduino ATmega32U4 (Micro)

Schematic used with Arduino Atmega328

__Click [here](https://github.com/pu2clr/VFO_BFO_OLED_ARDUINO/blob/master/Experiments/VFO_RADIO_CD2003GP/source/si5351_vfoCD2003GP_atmega32u4/si5351_vfoCD2003GP_atmega32u4.ino) to see the sketch used on Arduino ATmega32U4 (schematic above).__ 

## Radio based on CD2003GP

#### CD2003GP Block Diagram

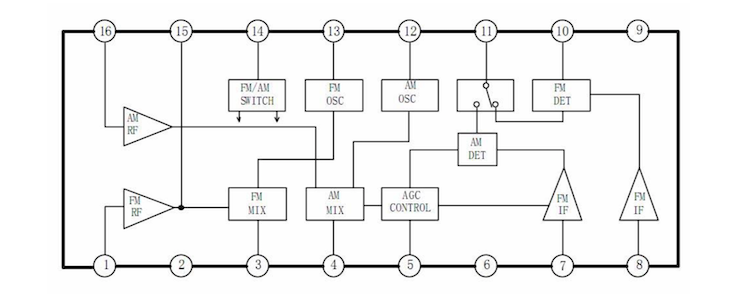
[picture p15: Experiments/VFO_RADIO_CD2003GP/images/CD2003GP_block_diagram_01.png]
Photo 1 - CD2003GP


[Source - CD2003GP Datasheet](http://www.datasheetcafe.com/cd2003gp-datasheet-pdf/)

#### Application Citcuit

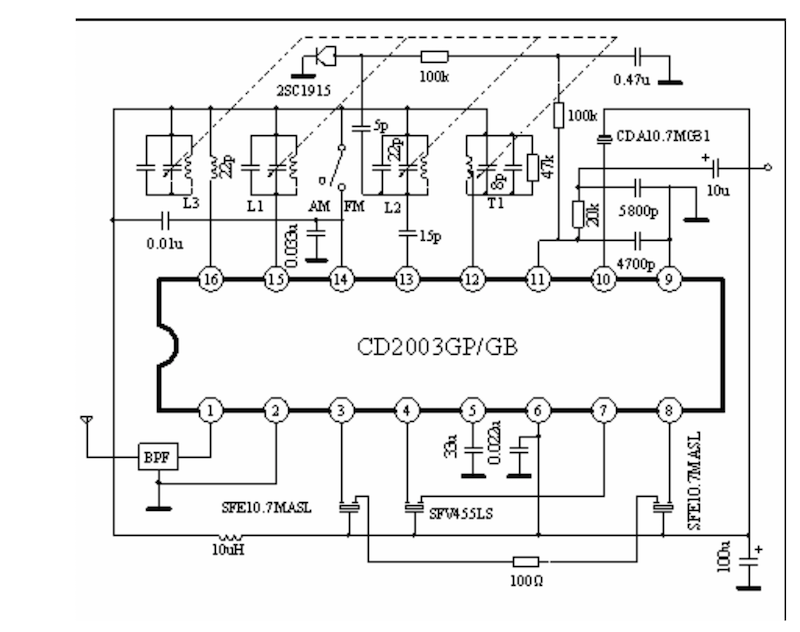
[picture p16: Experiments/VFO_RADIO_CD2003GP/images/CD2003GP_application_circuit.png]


[Source - CD2003GP Datasheet](http://www.datasheetcafe.com/cd2003gp-datasheet-pdf/)

#### Inexpensive Commercial Radio
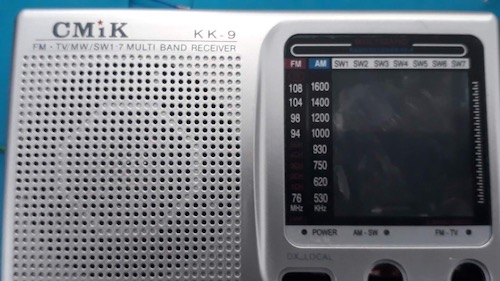
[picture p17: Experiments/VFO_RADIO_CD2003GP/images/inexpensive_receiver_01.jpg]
Photo 3 - Inexpensive commercial radio


#### Radio Modification

This experiment was based on a FM/AM commercial radio for receiving AM/FM broadcast station. 
In my first test, I isolated the pin 13 of the CD2003GP (could be also TA2003) and injected the signal from the si5351 output (CLK0). To connect the oscillator to pin 13, used a 15pf capacitor. It is the same capacitor used by the radio oscillator.

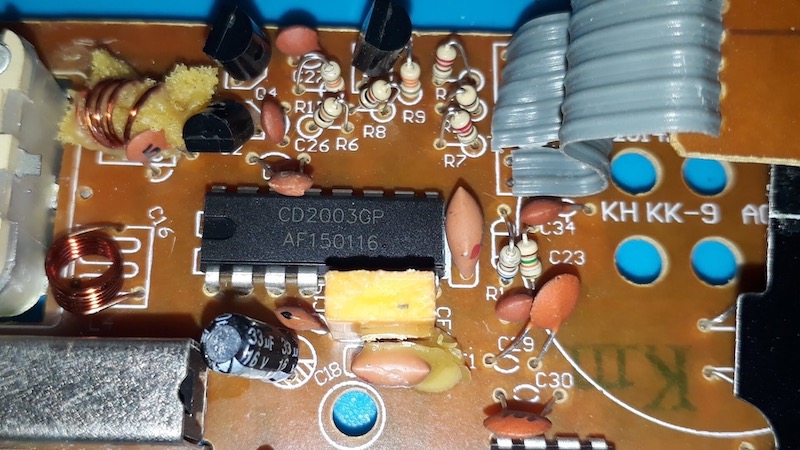
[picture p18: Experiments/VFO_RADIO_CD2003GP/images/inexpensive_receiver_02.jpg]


#### Sugested Modification

__IMPORTANTE__: Do not do this if you do not feel safe in doing so.

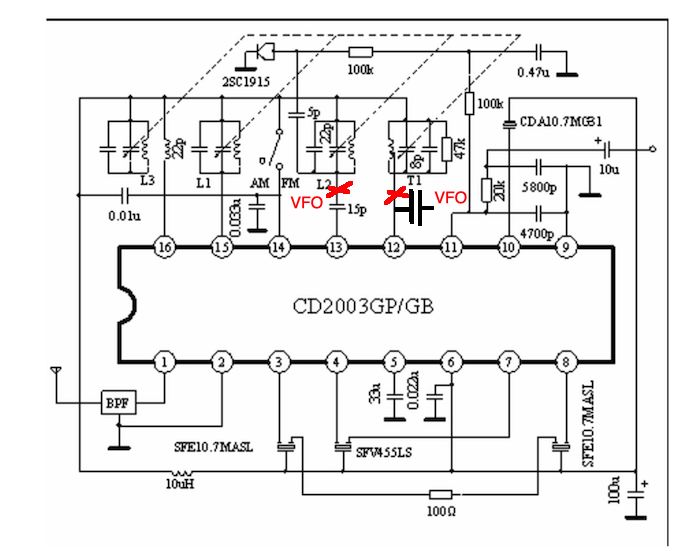
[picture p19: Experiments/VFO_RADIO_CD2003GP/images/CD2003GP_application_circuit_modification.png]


Photo 3 - Motification

#### Coupling

In my first test, I isolated the pin 13 of the CD2003GP (could be also TA2003) from the radio board and injected the signal from the si5351 output (CLK0). To connect the oscillator to pin 13, used a 15pf capacitor. It is the same capacitor used by the radio oscillator. The AM section was disabled in the receiver for this test.

Coupling 01

Coupling 02

Coupling 03

## Arduino Sketch 

Some original features of the VFO and BFO project was modified to adapt it better to the radio based on CD2003GP. The main modification was the band behaviour. The VFO implemented on Arduino Sketch has the follow information:  

- __Band name__ - Band name that will show on display;
- __Initial Freq.__ -  Lowest band frequency (1/100 Hz);
- __Final Freq.__ - highest frequency band (1/100 Hz);
- __offset__ - Shows on the display the frequency of the station and makes the signal generator to oscillate considering the IF (1/100 Hz);
- __Freq Unit__ - Frequency unit that will be show on the display for the current band;
- __Divider__ - Divider used to reduce the number of digits in the display;
- __decimals__ - number of decimal places after the comma;
- __Initial Step Index__ - Lowest step index used for the band (see Step table)
- __Final Step Index__ - Highest step index used for the band (see Step table) 
- __Start Step Index__ - Default step index used for the band (see Step table)
- __callback function__ - point to the function that handles specific things for the band

The implementation of the band information

```cpp
// Structure for Bands database
typedef struct
{
  char *name;
  uint64_t minFreq; // Min. frequency value for the band (unit 0.01Hz)
  uint64_t maxFreq; // Max. frequency value for the band (unit 0.01Hz)
  long long offset;
  char *unitFreq;         // MHz or KHz
  float divider;          // value that will be the divider of current clock (just to present on display)
  short decimals;         // number of digits after the comma
  short initialStepIndex; // Index to the initial step of incrementing
  short finalStepIndex;   // Index to the final step of incrementing
  short starStepIndex;    // Index to start step of incrementing
  void (*f)(void);        // pointer to the function that handles specific things for the band
} Band;
```

### Band Table 

| Band name | Initial Freq.  | Final Freq. | offset | Freq Unit | Divider | Dec. | Initial Step Index | Final Step Index | Default |
| --- | --- | --- | --- | ---| --- |--- | --- | --- | ---|
| MW | 50000000 | 170000000 | 45500000 |  KHz | 100000 | 2 | 3 | 6 | 5 |
| SW1  | 170000000 | 1000000000 | 45500000  | KHz | 100000 | 2 | 2 | 6 | 3 |
| SW2  | 1000000000 | 2000000000 | 45500000  | KHz | 100000 | 2 | 2 | 6 | 3 |
| SW3  | 2000000000 | 3000000000 | 45500000  | KHz | 100000 | 2 | 2 | 6 | 3 |
| VHF1 | 3000000000 | 7600000000 | 45500000  | KHz | 100000 | 2 | 2 | 7 | 3 |
| FM | 7600000000 | 10800000000 | 1075000000  | MHz |  100000000 | 1 | 6 | 8 | 7 |
| AIR  | 10800000000 | 13700000000 | 1075000000  | MHz | 100000000 | 2 | 2 | 8 | 5 |
| VHF2 | 13700000000 | 14400000000 | 1075000000  | MHz | 100000000 | 2 | 2 | 8 | 5 |
| 2M  | 14400000000 | 15000000000 | 1075000000  | MHz | 100000000 | 2 | 2 | 8 | 5 |
| VFH3 | 15000000000 | 16000000000 | 1075000000  | MHz| 100000000 | 2 | 2 | 8| 5 |

The code below implements the band table of the VFO for the radio used here. 
The values amBroadcast, fmBroadcast and NULL are function that execute some specific actions for the band. When the value is NULL, no action will be executed.  

```cpp
// Band database. You can change the band ranges if you need.
// The unit of frequency here is 0.01Hz (1/100 Hz). See Etherkit Library at https://github.com/etherkit/Si5351Arduino
Band band[] = {
    {"MW  ", 50000000LLU, 170000000LLU, 45500000LU, "KHz", 100000.0f, 0, 3, 6, 5, amBroadcast},
    {"SW1 ", 170000000LLU, 1000000000LLU, 45500000LU, "KHz", 100000.0f, 2, 1, 6, 3, amBroadcast},
    {"SW2 ", 1000000000LLU, 2000000000LLU, 45500000LU, "KHz", 100000.0f, 2, 1, 6, 3, amBroadcast},
    {"SW3 ", 2000000000LLU, 3000000000LLU, 45500000LU, "KHz", 100000.0f, 2, 1, 6, 3, amBroadcast},
    {"VHF1", 3000000000LLU, 7600000000LLU, 45500000LU, "KHz", 100000.0f, 2, 1, 7, 3, NULL},
    {"FM  ", 7600000000LLU, 10800000000LLU, 1075000000LLU, "MHz", 100000000.0f, 2, 6, 8, 7, fmBroadcast},
    {"AIR ", 10800000000LLU, 13700000000LLU, 1075000000LLU, "MHz", 100000000.0f, 3, 2, 8, 5, NULL},
    {"VHF2", 13700000000LLU, 14400000000LLU, 1075000000LLU, "MHz", 100000000.0f, 3, 2, 8, 5, NULL},
    {"2M  ", 14400000000LLU, 15000000000LLU, 1075000000LLU, "MHz", 100000000.0f, 3, 2, 8, 5, NULL},
    {"VFH3", 15000000000LLU, 16000000000LLU, 1075000000LLU, "MHz", 100000000.0f, 3, 2, 8, 5, NULL}};
```

### Step Table 

The step table is implemented by the code below.  Each band uses a subset of the band table. This will depend on the characteristics of the band.

```cpp
// Struct for step database
typedef struct
{
  char *name; // step label: 50Hz, 100Hz, 500Hz, 1KHz, 5KHz, 10KHz and 500KHz
  long value; // Frequency value (unit 0.01Hz See documentation) to increment or decrement
} Step;
```

```cpp 
// Steps database. You can change the Steps and numbers of steps here if you need.
Step step[] = {
    {"10Hz  ", 1000},
    {"100Hz ", 10000},
    {"500Hz ", 50000},
    {"1KHz  ", 100000},
    {"5KHz  ", 500000},
    {"10KHz  ",1000000},
    {"50KHz ", 5000000},
    {"100KHz", 10000000},
    {"500KHz", 50000000}};
```

| Step Index | Step name | Step Value (1/100 Hz) |
| --- | --- | --- |
| 0 | 10Hz | 1000 |
| 1 | 100Hz | 10000 |
| 2 | 500Hz | 50000 |
| 3 | 1KHz | 100000 |
| 4 | 5KHz | 500000 |
| 5 | 10KHz |  1000000 |
| 6 | 50KHz |  5000000 |
| 7 | 100KHz | 10000000 |
| 8 | 500KHz | 50000000 |

## Callback functions

This sketch uses callback functions to complement specific actions for a specific band.
For example, you will need to set the PIN 14 of the CD2003GP to HIGH if you want to work with FM.
In contrast, you need to set the PIN 14 to LOW if you want to work with AM.

The code below shows the callback functions declaration

```cpp
// Callback functions declarations
// Depending on the selected band, you may want to perform specific actions
// The functions declared below will do something for AM and FM BAND. See implementation later.
// You can implement callback function for other bands
void amBroadcast(); // See implementation later.
void fmBroadcast(); // See implementation later.
```

The callback functions above are referenced in band database (see Band band[]) above.

```cpp
// Callback implementation

// Doing something spefict for AM
// Example: set Pin 14 of the CD2003GP to LOW; switch filter, turn AM LED on etc
void amBroadcast()
{
  // TO DO
  STATUSLED(HIGH); // Just testing if it is working - Turn LED ON
}

// Doing something spefict for FM
// Example: set Pin 14 of the CD2003GP to HIGH; turn FM LED on etc
void fmBroadcast()
{
  // TO DO
  STATUSLED(LOW); // Just testing if it is working - Turn LED OFF
}
```

The code below shows the use of callback function when the use changes the band

```cpp
 if (digitalRead(BUTTON_BAND) == HIGH && (millis() - elapsedButton) > MIN_ELAPSED_TIME)
  {
    currentBand = (currentBand < lastBand) ? (currentBand + 1) : 0; // Is the last band? If so, go to the first band (AM). Else. Else, next band.
    vfoFreq = band[currentBand].minFreq;
    currentStep = band[currentBand].starStepIndex;

    // Call callback function if exist something to do for the specific  band
    if (band[currentBand].f != NULL)
      (band[currentBand].f)();

    isFreqChanged = true;
    elapsedButton = millis();
  }
```  

## Vídeos 

- [VFO and BFO project test with an inexpencive radio based on CD2003GP](https://youtu.be/_KgBc6vYWLg)
- [Testing the VFO with a CD2003GM HOMEBREW FM RECEIVER](https://youtu.be/JfgRjDK8LTE)
- [VFO and BFO remote control with iPhone via Bluetooth](https://youtu.be/7gBRUmsrCus)

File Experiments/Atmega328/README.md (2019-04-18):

# The BFO and VFO implemented on Atmega328 (without use of external interruptions)

If you have an Arduino UNO, Nano, Mini or other based on Atmega328, you might want to use this sketch instead the original.

The main modifications are: 

- No __valatile__ variable was declared;
- No external interrupt was used; 
- All Buttons devices are controlled on main loop.

__IMPORTANT__:
This sketch will not be updated. I mean, this system may not have the same functionality as the original sketch. The intent here is only to show you how to implement button controls without external interrupts resource.

## Schematic (Atmega328)

Suggested schematic to work with si5351, oled and Arduino Atmega328

Schematic VFO and BFO Si5351 Arduino Atmega 328

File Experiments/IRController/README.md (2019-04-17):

# IR Remote Control Implemetation for the VFO and BFO

## Schematic 

Suggested schematic to work with si5351, oled, IR and Arduino Atmega328

Schematic VFO And BFO with SI5351, OLED, IR and Arduino Atmega 328

Use the sketch [CheckYourRemoteControl.ino](https://github.com/pu2clr/VFO_BFO_OLED_ARDUINO/blob/master/Experiments/IRController/CheckYourRemoteControl/CheckYourRemoteControl.ino) to check your IR remote control. 

### IR Remote Control 

The photo below shows another kind the controle tha can be used. 

Photo IR Control 02

The table below shows the codes returned by each key. 

| Acation Key | One touch value | Keep Pressed |  Description |
| --- | ---  | ---  | --- |
| On/Off  | 12 | 2060 | | 
| Up | 32 	| 2080 | Next band | 
| Down | 33 		| 2081 | Previous Band | 
| MUTE | 13 		| 2061 | |
| LEFT | 17 | 2065 | Frequency increment | 
| RIGHT | 16 | 2064 | Frequency decrement | 
| AV/TV | 11 | 2059 | |

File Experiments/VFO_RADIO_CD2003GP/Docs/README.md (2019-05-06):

# Testando o VO e BFO em um rádio barato baseado no chip CD2003GP 

__Importante: Documentação ainda em construção__

Por PU2CLR - Ricardo
April, 2019

## Sumário

1. [Introdução](https://github.com/pu2clr/VFO_BFO_OLED_ARDUINO/tree/master/Experiments/VFO_RADIO_CD2003GP/Docs#introdução)
2. [Apresentação do Display](https://github.com/pu2clr/VFO_BFO_OLED_ARDUINO/tree/master/Experiments/VFO_RADIO_CD2003GP/Docs#apresentação-do-display)
3. [Esquema para Arduino baseado no Atmega328 (UNO, Pro Mini, Nano etc)](https://github.com/pu2clr/VFO_BFO_OLED_ARDUINO/tree/master/Experiments/VFO_RADIO_CD2003GP/Docs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)
4. [Esquema para Arduino baseado ATmega32U4 (Micro)](https://github.com/pu2clr/VFO_BFO_OLED_ARDUINO/tree/master/Experiments/VFO_RADIO_CD2003GP/Docs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)
5. [O Rádio baseado no CD2003GP utilizado no teste](https://github.com/pu2clr/VFO_BFO_OLED_ARDUINO/tree/master/Experiments/VFO_RADIO_CD2003GP/Docs#o-rádio-baseado-no-cd2003gp-utilizado-no-teste)
   1. [Diagrama de Bloco do CD2003GP](https://github.com/pu2clr/VFO_BFO_OLED_ARDUINO/tree/master/Experiments/VFO_RADIO_CD2003GP/Docs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)
   2. [Circúito de Aplicação](https://github.com/pu2clr/VFO_BFO_OLED_ARDUINO/tree/master/Experiments/VFO_RADIO_CD2003GP/Docs#circúito-de-aplicação)
   3. [Foto do Rádio](https://github.com/pu2clr/VFO_BFO_OLED_ARDUINO/tree/master/Experiments/VFO_RADIO_CD2003GP/Docs#foto-do-rádio)
   4. [Modificação no estágio de FM](https://github.com/pu2clr/VFO_BFO_OLED_ARDUINO/tree/master/Experiments/VFO_RADIO_CD2003GP/Docs#modificação-no-estágio-de-fm)
   5. [Acoplamento do si5351 no pino 13 do CD2003GP](https://github.com/pu2clr/VFO_BFO_OLED_ARDUINO/tree/master/Experiments/VFO_RADIO_CD2003GP/Docs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)
   6. [Sugestões para acoplamento](https://github.com/pu2clr/VFO_BFO_OLED_ARDUINO/tree/master/Experiments/VFO_RADIO_CD2003GP/Docs#sugestões-para-acoplamento)
6. [Arduino Sketch](https://github.com/pu2clr/VFO_BFO_OLED_ARDUINO/tree/master/Experiments/VFO_RADIO_CD2003GP/Docs#arduino-sketch)
   1. [Tabela de Bandas](https://github.com/pu2clr/VFO_BFO_OLED_ARDUINO/tree/master/Experiments/VFO_RADIO_CD2003GP/Docs#band-table)
   2. [Tabela de passos](https://github.com/pu2clr/VFO_BFO_OLED_ARDUINO/tree/master/Experiments/VFO_RADIO_CD2003GP/Docs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)
   3. [Função no estilo callback](https://github.com/pu2clr/VFO_BFO_OLED_ARDUINO/tree/master/Experiments/VFO_RADIO_CD2003GP/Docs#funções-no-estilo-callback)
   4. [Explicando o uso de sizeof](https://github.com/pu2clr/VFO_BFO_OLED_ARDUINO/tree/master/Experiments/VFO_RADIO_CD2003GP/Docs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)
   5. [Explicando as estruturas Band e Step](https://github.com/pu2clr/VFO_BFO_OLED_ARDUINO/tree/master/Experiments/VFO_RADIO_CD2003GP/Docs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)
   6. [Explicando como o Encoder está codificado](https://github.com/pu2clr/VFO_BFO_OLED_ARDUINO/tree/master/Experiments/VFO_RADIO_CD2003GP/Docs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á-codificado)
7. [Source folder](https://github.com/pu2clr/VFO_BFO_OLED_ARDUINO/tree/master/Experiments/VFO_RADIO_CD2003GP/source)
   1. [Arduino sketch para Atmega328 - si5351_vfoCD2003GP_atmega328.ino](https://github.com/pu2clr/VFO_BFO_OLED_ARDUINO/tree/master/Experiments/VFO_RADIO_CD2003GP/source/si5351_vfoCD2003GP_atmega328)
   2. [Arduino sketch para Atmega32U4 - si5351_vfoCD2003GP_atmega32u4.ino](https://github.com/pu2clr/VFO_BFO_OLED_ARDUINO/tree/master/Experiments/VFO_RADIO_CD2003GP/source/si5351_vfoCD2003GP_atmega32u4) 
   3. [Arduino sketch Atmega328 e Bluetooth BLE-HM10 - si5351_vfo_ble_atmega328.ino](https://github.com/pu2clr/VFO_BFO_OLED_ARDUINO/tree/master/Experiments/VFO_RADIO_CD2003GP/source/si5351_vfo_ble_atmega328)
   4. [Aplicativo para Celular Android e iOS para controlar o VFO](https://github.com/pu2clr/VFO_BFO_OLED_ARDUINO/tree/master/Experiments/VFO_RADIO_CD2003GP/source/vfoMobileApplication)
8.  [Vídeos](https://github.com/pu2clr/VFO_BFO_OLED_ARDUINO/tree/master/Experiments/VFO_RADIO_CD2003GP/Docs#v%C3%ADdeos)

## Introdução

Este teste modifica o sketch do Arduino original e apresenta duas versões. Há duas versões do sketch, uma para Arduino baseado no Atmega328 e outra para o Atmega32U4. 
O rádio utilizado neste teste é um CMik KK9, baseado no chip CD2003GP ou TA2003. Este rádio foi escolhido pela baixo custo de aquisição ( aproximadamente R$30,00). Trata-se de um receptor de Ondas Médias, Ondas Curtas e FM. Em MW e SW o rádio tem péssima seletividade. Contudo, a escuta de estações locais de AM é possível. Em FM o rádio se comporta um pouco melhor. 

Principais mudanças no sketch do Arduino

- Apresentação do Display 
- Quantidade reduzida de Bandas. Veja a [Tabela de Bandas a seguir]()
- Cada banda tem um comportamento diferente. Passos mais apropriados ee ações podem ser diferentes para bandas diferentes. 
- That is, frequency unit shown on the display and steps more suitable for the specific band. 

## Apresentação do Display

| Layout |  Layout |
| --- |  --- |
| Displau photo 1| Displau photo 2 |
| Displau photo 3| Displau photo 4 |

## Esquema para Arduino baseado no Atmega328 (UNO, Pro Mini, Nano etc)

Schematic used with Arduino Atmega328

__Click [here](https://github.com/pu2clr/VFO_BFO_OLED_ARDUINO/blob/master/Experiments/VFO_RADIO_CD2003GP/source/si5351_vfoCD2003GP_atmega328/si5351_vfoCD2003GP_atmega328.ino) to see the sketch used on Arduino Atmega328 (schematic above).__

## Esquema para Arduino baseado ATmega32U4 (Micro)

Schematic used with Arduino Atmega328

__Click [here](https://github.com/pu2clr/VFO_BFO_OLED_ARDUINO/blob/master/Experiments/VFO_RADIO_CD2003GP/source/si5351_vfoCD2003GP_atmega32u4/si5351_vfoCD2003GP_atmega32u4.ino) to see the sketch used on Arduino ATmega32U4 (schematic above).__ 

## O Rádio baseado no CD2003GP utilizado no teste

### Diagrama de Bloco do CD2003GP 

Photo 1 - CD2003GP

[Source - CD2003GP Datasheet](http://www.datasheetcafe.com/cd2003gp-datasheet-pdf/)

### Circúito de Aplicação

Photo 2 - CD2003GP

[Source - CD2003GP Datasheet](http://www.datasheetcafe.com/cd2003gp-datasheet-pdf/)

### Foto do Rádio
Photo 3 - Inexpensive commercial radio

### Modificação no estágio de FM

Este experimento foi baseado 

No primeiro teste foi isolado o pino 13 do chip CD2003GP e injetado o sinal da saída 0 do si5351 (CLK0). Para conectar essa saída no pino 13 foi utilizado o próprio capacitor de 15Pf que acopla o oscilador do próprio rádio. 

Photo 3 - Motification

#### Acomplamento do si5251 no pino 13 do si5351 

Photo 2 - CD2003GP

Photo 3 - Motification

#### Sugestões para acoplamento

No primeiro teste, a perna do capacitor de 15Pf que acopla o oscilador local ao pino 13 do CD2003GP foi dessolada, ficando o capacitor e o pino 13 isolado do rádio.  Assim, a perna dessoldada foi conectada à  ao VFO (saída do si5351 - CLK0). 

Coupling 01

Coupling 02

Coupling 03

## Arduino Sketch 

Esta seção apresenta alguns aspectos da programação do VFO e BFO.  É importante ressaltar que alguns recursos previstos neste sketch podem não ser implementados no rádio usado como exemplo. 

O centro das informações do VFO está armazenado em uma tabela seguintes informações para cada banda:  

| Atributo |  Descrição |  Variável | 
| --- | --- | --- |
| Nome da Banda | Nome da Banda que será apresentada no Display | *name |
| Freq. Inicial | Freqência inicial da Banda (1/100 Hz) | minFreq |
| Freq. Final | Freqência final (1/100 Hz) | maxFreq | 
| Deslocamento  | Deslocamento em 1/100Hz utilizado na banda para compensar a FI (1/100 Hz) | offset |
| Unidade | Unidade de freqência utilizada na Banda | *unitFreq |
| Divisor | Divisor usado para expressar a freqência utilizada na banda | divider | 
| Casas Decimais| Número de casas decimais depois da vírgula utilizada para a banda | decimals |
| Menor passo | Índice para o menor passo utilizado na banda (ver tabela de passos) | finalStepIndex | 
| Maior passo | Índice do maior passo utilizado na banda | finalStepIndex |
| Passo Padrão  | Índice do passo padrão da banda | starStepIndex |
| Função de chamada | Função que será executada quando uma banda for selecionada | *f |

A representação em C para as informações de uma banda no tipo definido __Band__.

```cpp
// Structure for Bands database
typedef struct
{
  char *name;
  uint64_t minFreq; // Min. frequency value for the band (unit 0.01Hz)
  uint64_t maxFreq; // Max. frequency value for the band (unit 0.01Hz)
  long long offset;
  char *unitFreq;         // MHz or KHz
  float divider;          // value that will be the divider of current clock (just to present on display)
  short decimals;         // number of digits after the comma
  short initialStepIndex; // Index to the initial step of incrementing
  short finalStepIndex;   // Index to the final step of incrementing
  short starStepIndex;    // Default Index for the band
  void (*f)(void);        // pointer to the function that handles specific things for the band
} Band;
```

### Tabela de Bandas

Um array da estrutura __Band__ é criado para representar todo o conjunto de bandas que serão trabalhadas no VFO. 

| Band name | Initial Freq.  | Final Freq. | offset | Freq Unit | Divider | Dec. | Initial Step Index | Final Step Index | Default |
| --- | --- | --- | --- | ---| --- |--- | --- | --- | ---|
| MW | 50000000 | 170000000 | 45500000 |  KHz | 100000 | 2 | 3 | 6 | 5 |
| SW1  | 170000000 | 1000000000 | 45500000  | KHz | 100000 | 2 | 2 | 6 | 3 |
| SW2  | 1000000000 | 2000000000 | 45500000  | KHz | 100000 | 2 | 2 | 6 | 3 |
| SW3  | 2000000000 | 3000000000 | 45500000  | KHz | 100000 | 2 | 2 | 6 | 3 |
| VHF1 | 3000000000 | 7600000000 | 45500000  | KHz | 100000 | 2 | 2 | 7 | 3 |
| FM | 7600000000 | 10800000000 | 1075000000  | MHz |  100000000 | 1 | 6 | 8 | 7 |
| AIR  | 10800000000 | 13700000000 | 1075000000  | MHz | 100000000 | 2 | 2 | 8 | 5 |
| VHF2 | 13700000000 | 14400000000 | 1075000000  | MHz | 100000000 | 2 | 2 | 8 | 5 |
| 2M  | 14400000000 | 15000000000 | 1075000000  | MHz | 100000000 | 2 | 2 | 8 | 5 |
| VFH3 | 15000000000 | 16000000000 | 1075000000  | MHz| 100000000 | 2 | 2 | 8| 5 |

O código a seguir implementa a tabela de banda para do VFO. 
O campo contendo __amBroadcast__, __fmBroadcast__ ou __NULL__ são referências para funções que executarão algumas ações específicas para a banda tão logo a banda seja selecionada. Quando a referência for __NULL__ para a banda, nenhuma função será executada. 

```cpp
// Band database. You can change the band ranges if you need.
// The unit of frequency here is 0.01Hz (1/100 Hz). See Etherkit Library at https://github.com/etherkit/Si5351Arduino
Band band[] = {
    {"MW  ", 50000000LLU, 170000000LLU, 45500000LU, "KHz", 100000.0f, 0, 3, 6, 5, amBroadcast},
    {"SW1 ", 170000000LLU, 1000000000LLU, 45500000LU, "KHz", 100000.0f, 2, 1, 6, 3, amBroadcast},
    {"SW2 ", 1000000000LLU, 2000000000LLU, 45500000LU, "KHz", 100000.0f, 2, 1, 6, 3, amBroadcast},
    {"SW3 ", 2000000000LLU, 3000000000LLU, 45500000LU, "KHz", 100000.0f, 2, 1, 6, 3, amBroadcast},
    {"VHF1", 3000000000LLU, 7600000000LLU, 45500000LU, "KHz", 100000.0f, 2, 1, 7, 3, NULL},
    {"FM  ", 7600000000LLU, 10800000000LLU, 1075000000LLU, "MHz", 100000000.0f, 2, 6, 8, 7, fmBroadcast},
    {"AIR ", 10800000000LLU, 13700000000LLU, 1075000000LLU, "MHz", 100000000.0f, 3, 2, 8, 5, NULL},
    {"VHF2", 13700000000LLU, 14400000000LLU, 1075000000LLU, "MHz", 100000000.0f, 3, 2, 8, 5, NULL},
    {"2M  ", 14400000000LLU, 15000000000LLU, 1075000000LLU, "MHz", 100000000.0f, 3, 2, 8, 5, NULL},
    {"VFH3", 15000000000LLU, 16000000000LLU, 1075000000LLU, "MHz", 100000000.0f, 3, 2, 8, 5, NULL}};
```

### Tabela de Passos

A tabela de passos foi implementada com um array de estrutura conforme mostrado a seguir. É importante ressaltar que cada pbanda usar somente um subconjunto de passos contidos na tabela. Este subconjunto está definido na tabela de bandas (band[]).

```cpp
// Struct for step database
typedef struct
{
  char *name; // step label: 50Hz, 100Hz, 500Hz, 1KHz, 5KHz, 10KHz and 500KHz
  long value; // Frequency value (unit 0.01Hz See documentation) to increment or decrement
} Step;
```

```cpp 
// Steps database. You can change the Steps and numbers of steps here if you need.
Step step[] = {
    {"10Hz  ", 1000},
    {"100Hz ", 10000},
    {"500Hz ", 50000},
    {"1KHz  ", 100000},
    {"5KHz  ", 500000},
    {"10KHz  ",1000000},
    {"50KHz ", 5000000},
    {"100KHz", 10000000},
    {"500KHz", 50000000}};
```

Os atributos __initialStepIndex__, __finalStepIndex__ e  __starStepIndex__, armazenam os índices do array __step[]__.    

| Step Index | Step name | Step Value (1/100 Hz) |
| --- | --- | --- |
| 0 | 10Hz | 1000 |
| 1 | 100Hz | 10000 |
| 2 | 500Hz | 50000 |
| 3 | 1KHz | 100000 |
| 4 | 5KHz | 500000 |
| 5 | 10KHz |  1000000 |
| 6 | 50KHz |  5000000 |
| 7 | 100KHz | 10000000 |
| 8 | 500KHz | 50000000 |

### Funções no estilo callback

As tabelas anteriores buscam oferecer dados sobre cada banda de tal forma que o processamento levará em consideração esses dados para realizar ações pertinentes a banda em uso. No entanto, para desempenhar ações de mais baixo nível, optou-se por utilizar funções no estilo "callback". Uma chamada callback é um recurso muito utilizado onde uma função é passada como argumento para outra função poder executá-la. No nosso exemplo, as funções no estilo "callback" não são enviadas como parâmetros. Na realidade, a tabela de bandas possui referências para funções que deverá ser chamada para complementar alguma ação específica para a banda em uso. Por exemplo, para acionar AM no rádio baseado no CD2003GP, é necessário colocar o pino 14 do chip em nível lógico baixo. Em contrapartida, para acionar FM no rádio, é necessário que o pino 14 do CD2003GP esteja em nível lógico alto. 
Se nenhuma ação precisa ser executada para a banda específica, o valor NULO (NULL) é atribuído à informação. 

O código a seguir ilustra a utilização da funções no estilo "callback".

```cpp
// Callback functions declarations
// Depending on the selected band, you may want to perform specific actions
// The functions declared below will do something for AM and FM BAND. See implementation later.
// You can implement callback function for other bands
void amBroadcast(); // See implementation later.
void fmBroadcast(); // See implementation later.
```
As funções declaradas anteriormente são referênciadas na estrutura de bandas (veja o array band[]).

```cpp
// Callback implementation

// Doing something spefict for AM
// Example: set Pin 14 of the CD2003GP to LOW; switch filter, turn AM LED on etc
void amBroadcast()
{
  // TO DO
  STATUSLED(HIGH); // Just testing if it is working - Turn LED ON
}

// Doing something spefict for FM
// Example: set Pin 14 of the CD2003GP to HIGH; turn FM LED on etc
void fmBroadcast()
{
  // TO DO
  STATUSLED(LOW); // Just testing if it is working - Turn LED OFF
}
```

Note no código a seguir que se a banda possuir uma função no estilo "callback" (diferente de nulo - band[currentBand].f != NULL), então a função é executada. 

```cpp
 if (digitalRead(BUTTON_BAND) == HIGH && (millis() - elapsedButton) > MIN_ELAPSED_TIME)
  {
    currentBand = (currentBand < lastBand) ? (currentBand + 1) : 0; // Is the last band? If so, go to the first band (AM). Else. Else, next band.
    vfoFreq = band[currentBand].minFreq;
    currentStep = band[currentBand].starStepIndex;

    // Call callback function if exist something to do for the specific  band
    if (band[currentBand].f != NULL)
      (band[currentBand].f)();

    isFreqChanged = true;
    elapsedButton = millis();
  }
```  

### Explicando o uso de sizeof

o sizeof é um operador muito utilizado no C para obter o tamanho em bytes de estruturas de dados, array e tipos primitivos de dados (int, char, long etc). 
Por exemplo: 
long x =  1L;  
int tamanhoX = sizeof x; 

Na maioria das arquiteturas de hardware, é o mesmo que atribuir 4 à variável tamanhoX (explico o porquê do uso adiante).
 
Note no programa foi criado um tipo definido (typedef) para representar as informações de uma banda. Exemplo: 
 
```cpp
typedef struct
{
  char *name;
  uint64_t minFreq; // Min. frequency value for the band (unit 0.01Hz)
  uint64_t maxFreq  // Max. frequency value for the band (unit 0.01Hz)
} Band;
``` 
 
Que tamanho tem o tipo definido Band acima? 
 
Tamanho da variável Band é:  (o tamanho do ponteiro char para nome) + (o tamanho de minFreq) + (o tamanho de maxFreq) 
 
- o tamanho de uma ponteiro é normalmente 4 bytes (para a maioria das arquiteturas de hardware);
- o tamanho de minFreq é 8 bytes (64 bits); e
- o tamanho de maxFreq também é 8 bytes.  
 
Diante disso, o tamanho do tipo definido que foi criado seria: 4 + 8 + 8 = 20 bytes. 
 
#### Por que usar o operador sizeof? 
 
Há várias razões.
 
1.     Dispensa o cálculo do tamanho em bytes da estrutura ou tipo de dados que você estiver usando. Em tempo de compilação, o compilador fará a conversão é trabalhará com o tamanho correto considerando a plataforma de hardware corrente.  
2.     Deixa o código mais fácil de manter. Por exemplo, imagine  que eu queira incluir mais um atributo na minha estrutura conforme mostrado a seguir
```cpp 
typedef struct
{
  char *name;
  uint64_t minFreq; // Min. frequency value for the band (unit 0.01Hz)
  uint64_t maxFreq; // Max. frequency value for the band (unit 0.01Hz)
  uint64_t offset;
} Band;
```

Observe no código acima a inclusão de __offset__. A mudança mostrada no código acima, não demanda a necessidade de recalcular o novo tamanho da estrutura se for usado sizeof. Isto é, sizeof agora retornará 28 bytes.  
 1.     Facilita a migração do código para outras plataformas de microcontroladores. Outros microcontroladores podem usar tamanho padrões de tipos primitivos diferentes do Arduino, por exemplo. Há plataformas que o tipo int é de 32 bits (4 bytes)  e não 16 bits (2 bytes) e há plataformas que usam diferentes tamanhos para ponteiros (dependendo como essas plataformas trabalham com endereçamento de memória).  Com o uso do sizeof, eu não preciso me preocupar com isso neste contexto (tamanho em bytes).
 
#### Qual o objetivo do sizeof no sketch? 
 
A principal razão é a tabela de bandas. Veja o exemplo a seguir: 

```cpp 
// Band database. You can change the band ranges if you need.
// The unit of frequency here is 0.01Hz (1/100 Hz). See Etherkit Library at https://github.com/etherkit/Si5351Arduino
Band band[] = {
    {"MW   ", 50000000LLU, 170000000LLU, 45500000LU},
    {"SW1  ", 700000000LLU, 1000000000LLU, 45500000LU},
    {"SW1  ", 1000000000LLU, 2000000000LLU, 45500000LU},
    {"FM   ", 7600000000LLU, 10800000000LLU, 1075000000LLU},
    {"AIR  ", 10800000000LLU, 13500000000LLU, 1075000000LLU},
    {"VFH  ", 13500000000LLU, 16000000000LLU, 1075000000LLU}}; 
``` 
Note que o array band[] é do tipo Band (o tipo definido que foi criado). 
O  objetivo é saber quantos elementos tem esse array band[]. 
Você agora deve pensar: ora, é só contar. E se fizer isso encontrará 5. 
Naturalmente você poderia fazer isso: 
```cpp 
Band band[5] = {
    {"MW   ", 50000000LLU, 170000000LLU, 45500000LU},
    {"SW1  ", 700000000LLU, 1000000000LLU, 45500000LU},
    {"SW1  ", 1000000000LLU, 2000000000LLU, 45500000LU},
    {"FM   ", 7600000000LLU, 10800000000LLU, 1075000000LLU},
    {"AIR  ", 10800000000LLU, 13500000000LLU, 1075000000LLU},
    {"VFH  ", 13500000000LLU, 16000000000LLU, 1075000000LLU}}; 
```

Bom, isso não estaria errado e muitos programadores fazem assim. Porém, a cada vez que você mudar essa tabela (e isso normalmente ocorre várias vezes), você deverá alterar também a quantidade de elementos do array band e ainda considerar essa nova quantidade em todo o código onde você precisar usá-la.
 
Para evitar esse desconforto e preocupação eu uso a expressão a seguir: 

const int lastBand = (sizeof band / sizeof(Band)) - 1;
 
#### O que ela faz? 
 
Calcula o número de elementos do array band[] e subtrai de 1 porque 4 é o último elemento do array (lembre-se que em C o primeiro elemento é o 0). 

(sizeof band / sizeof(Band)) => Considerando o primeiro exemplo do tipo Band seria: (20 + 20 + 20 + 20 + 20) / 20 = 100 / 20 = 5 ou
considerando o segundo exemplo do tipo definido  Band seria (28 + 28 + 28 + 28 +28) / 28 = 140 / 28 = 5. 

Note que mesmo mudando a estrutura do tipo Band, o resultado do tamanho continuou 5 elementos. Com isso, posso aumentar o número de linhas da tabela (inserir mais bandas), incluir novos atributos (variáveis) e não precisarei fazer nada no resto do código. Em princípio, isso pode parecer complicado, porém, na proporção que os requisitos do sistema ficam mais complexos, essa abordagem pode ajudar.
 
Só mais uma coisa que talvez possa gerar dúvida: 
 
As constantes “MW.  “, “SW1 “, “FM  “ etc.. NÃO fazem parte da estrutura implícita do array do tipo definido Band. A estrutura apenas armazena ponteiros para estas constantes. Em outras palavras, elas não são somadas ao tamanho em bytes da estrutura. Apenas os ponteiros para essas constantes são.
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

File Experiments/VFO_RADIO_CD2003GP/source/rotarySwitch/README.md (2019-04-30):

com.redwhitesilver.rotarySwitch
===============================

Rotary switch plugin for jQuery

### Documentation and examples:

[rotaryswitch.redwhitesilver.com](http://rotaryswitch.redwhitesilver.com)

### Licence

Apache 2.0

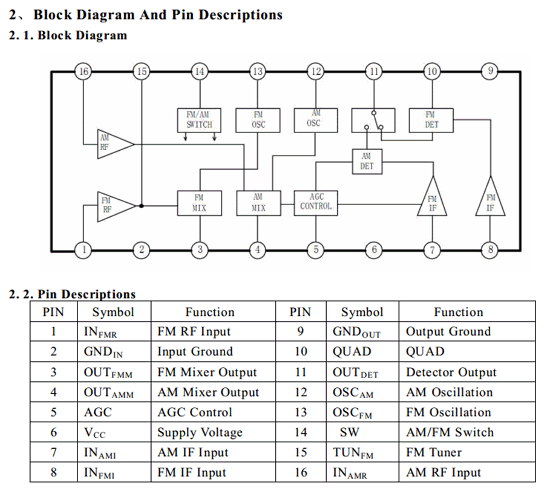
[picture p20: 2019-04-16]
Experiments/VFO_RADIO_CD2003GP/images/CD2003GP-Datasheet.png

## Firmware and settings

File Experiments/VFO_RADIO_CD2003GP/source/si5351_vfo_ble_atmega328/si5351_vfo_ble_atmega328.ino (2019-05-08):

/*
  Program to control the "Adafruit Si5351A Clock Generator" or similar via Arduino.
  This program control the frequencies of two clocks (CLK) output of the Si5351A
  The CLK 0 can be used as a VFO (535KHz to 160MHz)
  The CLK 1 can be used as a BFO (400KHz to 500KHz)

  Testing Bluetooth BLE connection and control
  
  See on https://github.com/etherkit/Si5351Arduino  and know how to calibrate your Si5351
  See also the example Etherkit/si5251_calibration
  Author: Ricardo Lima Caratti (PU2CLR) -   April, 2019
*/

#include <si5351.h>
#include <Wire.h>
#include <SSD1306Ascii.h>
#include <SSD1306AsciiAvrI2c.h>
#include <SoftwareSerial.h>

#define BLUETOOTH_TX 11
#define BLUETOOTH_RX 10

// Initiate BLE (HM10) Instance
SoftwareSerial ble(BLUETOOTH_TX, BLUETOOTH_RX);

// Enconder PINs
#define ENCODER_PIN_A 5 // Arduino  Pin 5
#define ENCODER_PIN_B 6 // Arduino  Pin 6

// OLED Diaplay constants
#define I2C_ADDRESS 0x3C
#define RST_PIN -1 // Define proper RST_PIN if required.

// Change this value below  (CORRECTION_FACTOR) to 0 if you do not know the correction factor of your Si5351A.
#define CORRECTION_FACTOR 70000 // See how to calibrate your Si5351A (0 if you do not want).

#define BUTTON_STEP    4    // Control the frequency increment and decrement
#define BUTTON_BAND    3    // Controls the band
#define BUTTON_VFO_BFO 2    // Switch VFO to BFO

// BFO range for this project is 400KHz to 500KHz. The central frequency is 455KHz.
#define MAX_BFO 45800000LU    // BFO maximum frequency
#define CENTER_BFO 45500000LU // BFO centeral frequency
#define MIN_BFO 45200000LU    // BFO minimum frequency

#define CD2003GP_SWITCH_AM_FM 7 // Define Arduino Pin 10 to switch AM and FM on CD2003GO based radio (connected to PIN 14 on the CD2003GP)
#define CD2003GP_AM_LED 8       // Indicate that the radio is working in AM mode
#define CD2003GP_FM_LED 9       // Indicate that the radio is working in FM mode

#define STATUS_LED 13 // Arduino status LED Pin 10
#define STATUSLED(ON_OFF) digitalWrite(STATUS_LED, ON_OFF)
#define MIN_ELAPSED_TIME 300

// OLED - Declaration for a SSD1306 display connected to I2C (SDA, SCL pins)
SSD1306AsciiAvrI2c display;

// The Si5351 instance.
Si5351 si5351;

// Callback functions declarations
// Depending on the selected band, you may want to perform specific actions
// The functions declared below will do something for AM and FM BAND. See implementation later.
// You can implement callback function for other bands
void amBroadcast();      // See implementation later.
void fmBroadcast();      // See implementation later.
void defultFinishBand(); //

// Structure for Bands database
typedef struct
{
  char *name;
  uint64_t minFreq; // Min. frequency value for the band (unit 0.01Hz)
  uint64_t maxFreq; // Max. frequency value for the band (unit 0.01Hz)
  long long offset;
  char *unitFreq;         // MHz or KHz
  float divider;          // value that will be the divider of current clock (just to present on display)
  short decimals;         // number of digits after the comma
  short initialStepIndex; // Index to the initial step of incrementing
  short finalStepIndex;   // Index to the final step of incrementing
  short starStepIndex;    // Default Index for the band
  void (*fstart)(void);   // pointer to the function that will handle specific things for the band immediately after the band is selected
 } Band;

// Band database. You can change the band ranges if you need.
// The unit of frequency here is 0.01Hz (1/100 Hz). See Etherkit Library at https://github.com/etherkit/Si5351Arduino
 Band band[] = {
     {"MW  ", 50000000LLU, 170000000LLU, 45500000LU, "KHz", 100000.0f, 0, 3, 6, 5, amBroadcast},
     {"SW1 ", 170000000LLU, 1000000000LLU, 45500000LU, "KHz", 100000.0f, 2, 1, 6, 3, amBroadcast},
     {"SW2 ", 1000000000LLU, 2000000000LLU, 45500000LU, "KHz", 100000.0f, 2, 1, 6, 3, amBroadcast},
     {"SW3 ", 2000000000LLU, 3000000000LLU, 45500000LU, "KHz", 100000.0f, 2, 1, 6, 3, amBroadcast},
     {"VHF1", 3000000000LLU, 7600000000LLU, 45500000LU, "KHz", 100000.0f, 2, 1, 7, 3, defultFinishBand},
     {"FM  ", 7600000000LLU, 10800000000LLU, 1070000000LLU, "MHz", 100000000.0f, 2, 6, 8, 7, fmBroadcast},
     {"FM1 ", 8600000000LLU, 10800000000LLU, 1075000000LLU, "MHz", 100000000.0f, 2, 5, 8, 7, fmBroadcast},
     {"AIR ", 10800000000LLU, 13700000000LLU, 1070000000LLU, "MHz", 100000000.0f, 3, 2, 8, 5, defultFinishBand},
     {"VHF2", 13700000000LLU, 14400000000LLU, 1070000000LLU, "MHz", 100000000.0f, 3, 2, 8, 5, defultFinishBand},
     {"2M  ", 14400000000LLU, 15000000000LLU, 1070000000LLU, "MHz", 100000000.0f, 3, 2, 8, 5, defultFinishBand},
     {"VFH3", 15000000000LLU, 16000000000LLU, 1070000000LLU, "MHz", 100000000.0f, 3, 2, 8, 5, defultFinishBand}};
 // Calculate the last element position (index) of the array band
 const int lastBand = (sizeof band / sizeof(Band)) - 1; // For this case will be 26.
 short currentBand = 0;                                 // First band. For this case, AM is the current band.

 // Struct for step database
 typedef struct
 {
   char *name; // step label: 50Hz, 100Hz, 500Hz, 1KHz, 5KHz, 10KHz and 500KHz
   long value; // Frequency value (unit 0.01Hz See documentation) to increment or decrement
} Step;

// Steps database. You can change the Steps and numbers of steps here if you need.
Step step[] = {
    {"10Hz  ", 1000},
    {"100Hz ", 10000},
    {"500Hz ", 50000},
    {"1KHz  ", 100000},
    {"5KHz  ", 500000},
    {"10KHz  ", 1000000},
    {"50KHz ", 5000000},
    {"100KHz", 10000000},
    {"500KHz", 50000000}};

// Calculate the index of last position of step[] array (in this case will be 8)
const short lastStepVFO = (sizeof step / sizeof(Step)) - 1; // index for max increment / decrement for VFO
short lastStepBFO = 3;                                      // index for max. increment / decrement for BFO. In this case will be is 1KHz
uint64_t bfoFreq = CENTER_BFO;                              // 455 KHz for this project

boolean isFreqChanged = true;
boolean clearDisplay = false;

// LW/MW is the default band
uint64_t vfoFreq = band[currentBand].minFreq;        // VFO starts on MW
short currentStep = band[currentBand].starStepIndex; // Step starts on default MW

// VFO is the Si5351A CLK0
// BFO is the Si5351A CLK1
short currentClock = 0; // If 0, then VFO will be controlled else the BFO will be

long elapsedButton = millis(); // will control the minimum time to process an interrupt action
long elapsedTimeEncoder = millis();

// Encoder variable control
unsigned char encoder_pin_a;
unsigned char encoder_prev = 0;
unsigned char encoder_pin_b;
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

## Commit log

2019-03-14 organizing folders
    [vfobfo_schematic.fzz]
2019-03-16 Ajustes no circito e mudanças no encoder
2019-03-18 Try fix the encoder debounce
    [si5351_vfobfo.ino]
2019-03-20 Improving documentation
    [bandas_freq.csv]
2019-03-20 documentation improviment
    [vfobfo_schematic.fzz]
2019-03-21 encoder improviments
2019-03-21 encoder problem soved
2019-03-21 encoder problem solved and documentation improvement
    [si5351_vfobfo.ino]
2019-03-21 improvement encoder and documentation
2019-03-21 Encoder and Documentation improvements
2019-03-21 schematic, documentation and code improvements.
    [vfo_bfo_pu2clr.sch, vfobfo_schematic.fzz]
2019-03-26 Arduino source
2019-03-28 Arduino sketch
2019-04-15 Experiments and Applications
    [bfo_schematic.fzz]
2019-04-27 VFO Mobile Application
    [coupling_CD2003GP.fzz]
2019-05-02 BLE Arduino Sketch
2019-05-06 Arduino BLE sketch
